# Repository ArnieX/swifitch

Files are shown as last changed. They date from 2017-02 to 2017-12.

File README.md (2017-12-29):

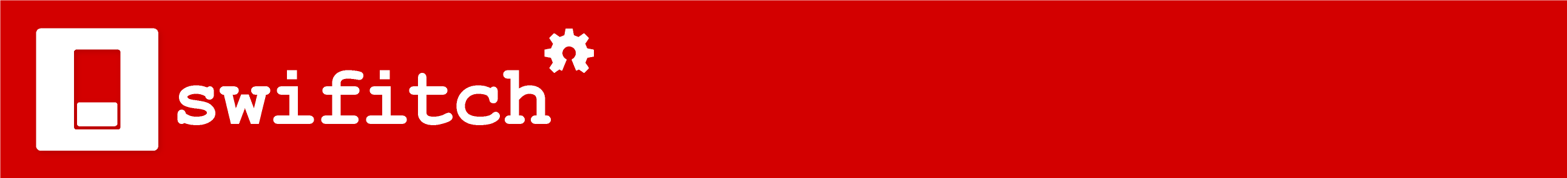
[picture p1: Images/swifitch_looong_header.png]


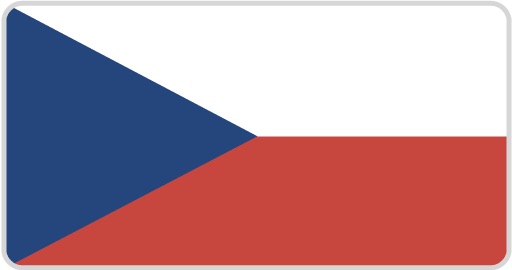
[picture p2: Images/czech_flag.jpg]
||[Readme v Češtině](https://github.com/ArnieX/swifitch/blob/master/README_CZ.md)|
|---|---|

## Table of contents

- [Introduction](https://github.com/ArnieX/swifitch#introduction)
	- [What is it?](https://github.com/ArnieX/swifitch#what-is-it)
	- [What can it do?](https://github.com/ArnieX/swifitch#what-can-it-do)
	- [What is expected cost?](https://github.com/ArnieX/swifitch#what-is-expected-cost)
	- [How does it look like?](https://github.com/ArnieX/swifitch#how-does-it-look-like)
	- [How big is it?](https://github.com/ArnieX/swifitch#how-big-is-it)
	- [Is it safe?](https://github.com/ArnieX/swifitch#is-it-safe)
	- [OK I'm sold! What do I need to build it?](https://github.com/ArnieX/swifitch#ok-im-sold-what-do-i-need-to-build-it)
- [SeeedStudio Fusion PCB](https://github.com/ArnieX/swifitch#seeedstudio-fusion-pcb)
	- [How to order PCBs](https://github.com/ArnieX/swifitch#how-to-order-pcbs)
-  [After you build it](https://github.com/ArnieX/swifitch#after-you-build-it)
	- [OK DONE! What's next?](https://github.com/ArnieX/swifitch#ok-done-whats-next)
- [Software](https://github.com/ArnieX/swifitch#software)
	- [Swifitch default software](https://github.com/ArnieX/swifitch#swifitch-default-software)
	- [Custom software](https://github.com/ArnieX/swifitch#custom-software)
- [Enclosure](https://github.com/ArnieX/swifitch#enclosure)
	- [3D Printed](https://github.com/ArnieX/swifitch#3d-printed)
	- [Purchased ABS box](https://github.com/ArnieX/swifitch#purchased-abs-box)
- [Soldering cheatsheet](https://github.com/ArnieX/swifitch#soldering-cheatsheet)
	- [Back side](https://github.com/ArnieX/swifitch#back-side)
	- [Front side](https://github.com/ArnieX/swifitch#front-side)
- [Credits](https://github.com/ArnieX/swifitch#credits)
- [What's next?](https://github.com/ArnieX/swifitch#whats-next)
- [Photos](https://github.com/ArnieX/swifitch#photos)

# Introduction

### What is it?

ESP8266 based WiFi enabled relay board, that will let you easily turn any light or any plug to SMART one. Easily control using HomeKit (other HW needed) or using any MQTT based SmartHome application. Or if you are skilled developer, write any code you want.

### What can it do?

Main purpose is to turn things ON or OFF. But it can do lot more than that, swifitch is equiped with header to connect another 4 digital devices and 1 analog. These could be sensors etc.

If you need, by sacrificing one of the data pins, you can get 5V for your 5V sensors.

**⛔  Be aware that swifitch's pins are not 5V tolerant and cannot accept 5V on any of the pins provided, and it will damage the ESP.**

There are also two jumpers. One is for enabling deep sleep and the other is to put ESP into flash mode when you use conventional USB2UART programmer. We have reused one NodeMCU to make a lot more convenient programmer out of it, because it handles resets and flash mode boot automatically. Details will follow.

### What is expected cost?

We have designed swifitch to be both cheap and safe. So it is not ultra cheap but not expensive too. **Our cost calculations has stoped at $8!** Not bad, what you think?

### How does it look like?

Definitely beautiful!!

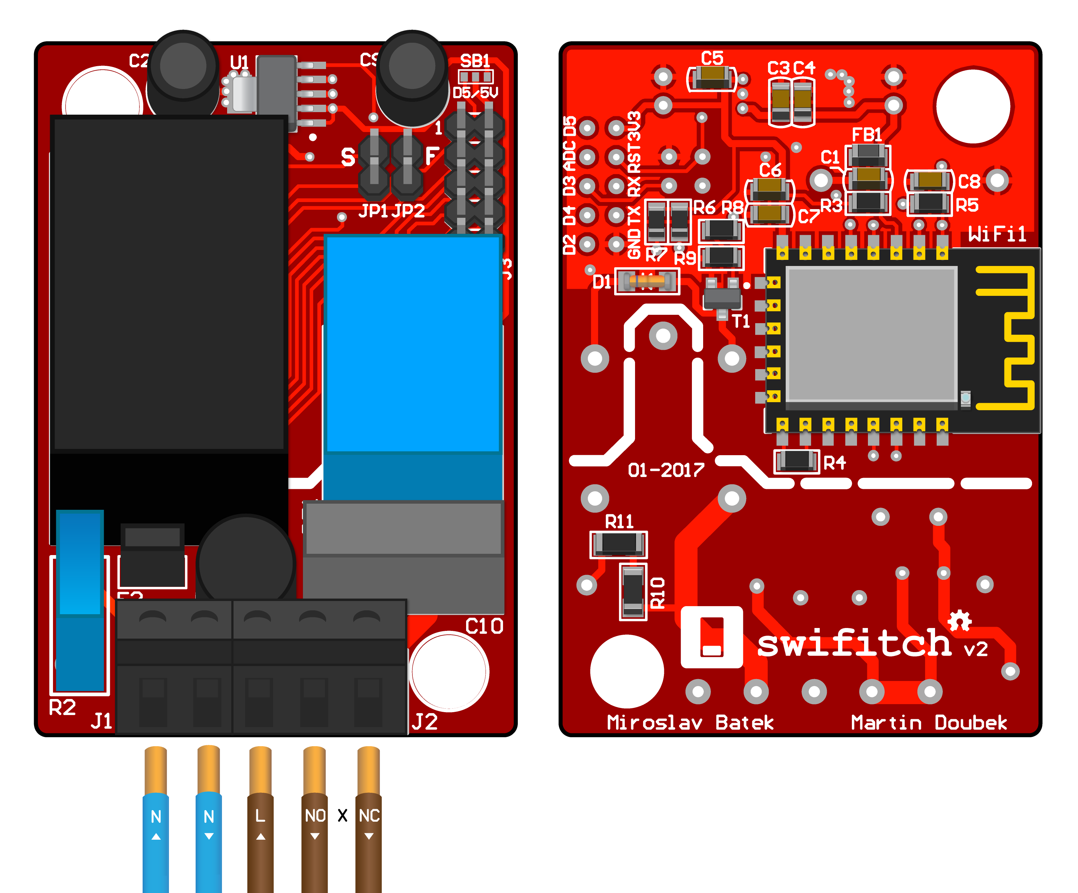
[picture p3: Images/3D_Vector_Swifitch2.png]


### How big is it?

Actually very small, you should be able to fit it almost anywhere without any hassle. But I know, numbers tell it all, so here it is.

|**Width**|**Height**|**Depth**|**Weight W/O BOX**|**Weight W/ BOX**|
|---|---|---|---|---|
| 42mm / 1.65" | 60.5mm / 2.36" | 19.6mm / 0.77" | ~42g / ~1.48oz | ~72g / ~2.54oz  |

### Is it safe?

We have designed few safety features in swifitch. Most important are fuses on mains input. There is one overcurrent fuse and one overvoltage fuse (surge protection), and more importantly temperature fuse that will disconnect swifitch from mains input when temperature raises above 100°C. There should be another few safeties in HLK-PM01 but we didn't want to depend on it's quality. 

### OK I'm sold! What do I need to build it?

**Capacitors**

|Preview|Part|Buy|
|---|---|---|
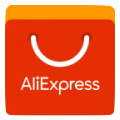
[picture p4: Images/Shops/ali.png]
||4.7μF 0805|[](http://swifitch.cz/capacitors_4.7uf_0805)|
||100nF 0805|[](http://swifitch.cz/capacitors_100nf_0805)|
||10nF 0805|[](http://swifitch.cz/capacitory_10nf_0805)|
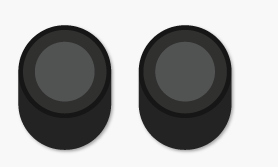
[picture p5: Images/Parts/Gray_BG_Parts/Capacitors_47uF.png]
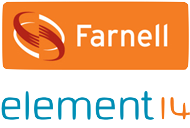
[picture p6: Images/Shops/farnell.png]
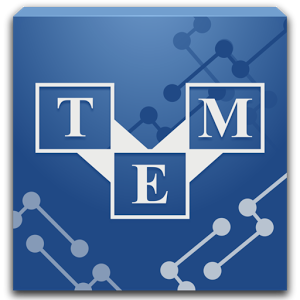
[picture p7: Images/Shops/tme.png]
||47μF ⌀6.3x5mm|[](http://swifitch.cz/capacitors_47uf_6.3x5_farnell) [](http://swifitch.cz/capacitors_47uf_6.3x5_tme)|
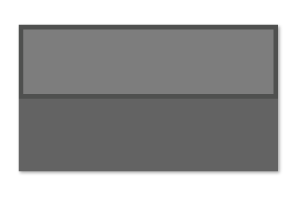
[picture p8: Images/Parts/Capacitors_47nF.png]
||47nF X2|[](http://swifitch.cz/capacitors_47nf_farnell) [](http://swifitch.cz/capacitors_47nf_tme)|

**Resistors**

|Preview|Part|Buy|
|---|---|---|
||10kΩ 0805|[](http://swifitch.cz/resistors_10k_0805)|
||1.5kΩ 0805|[](http://swifitch.cz/resistors_1.5k_0805)|
||2.2kΩ 0805|[](http://swifitch.cz/resistors_2.2k_0805)|
||47kΩ 0805|[](http://swifitch.cz/resistors_47k_0805)|
||160Ω 1206|[](http://swifitch.cz/resistors_160R_1206)|
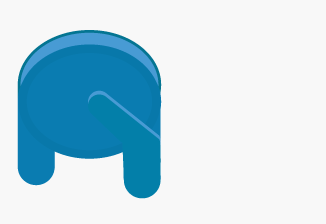
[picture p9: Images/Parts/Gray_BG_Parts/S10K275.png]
||S10K275|[](http://swifitch.cz/resistors_S10K275_farnell) [](http://swifitch.cz/resistors_S10K275_tme)|

**Power and Controls**

|Preview|Part|Buy|
|---|---|---|
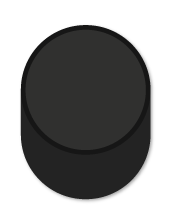
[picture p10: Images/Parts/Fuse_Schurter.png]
||SCHURTER MST 250VAC 500mA|[](http://swifitch.cz/power_schurter_fuse_farnell) [](http://swifitch.cz/power_schurter_fuse_tme)|
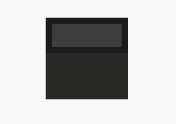
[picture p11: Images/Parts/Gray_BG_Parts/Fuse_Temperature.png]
||PROFFUSE TZ-P100/2 100°C or similar|[](http://swifitch.cz/power_temperature_fuse_farnell) [](http://swifitch.cz/power_temperature_fuse_tme)|
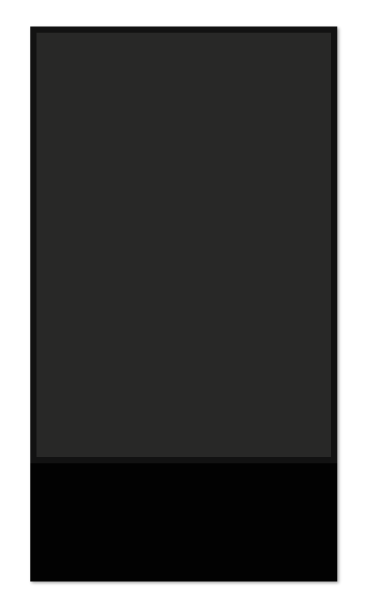
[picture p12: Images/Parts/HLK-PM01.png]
||Hi-Link HLK-PM01 AC-DC 5V/3W|[](http://swifitch.cz/power_AC_DC)|
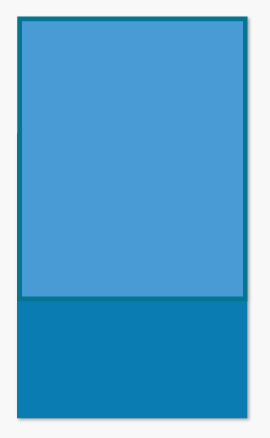
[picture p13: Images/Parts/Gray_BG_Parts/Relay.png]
||SRD-05VDC-SL-C Relay<br>FINDER  36.11.9.005.4011|[](http://swifitch.cz/power_relay_ali) [](http://swifitch.cz/power_relay_farnell) [](http://swifitch.cz/power_relay_tme)|

**Other SMD Parts**

|Preview|Part|Buy|
|---|---|---|
||BC817-16.215|[](http://swifitch.cz/smd_bc817_ali) [](http://swifitch.cz/smd_bc817_farnell) [](http://swifitch.cz/smd_bc817_tme)|
||BAS86|[](http://swifitch.cz/smd_bas86_farnell) [](http://swifitch.cz/smd_bas86_tme)|
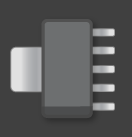
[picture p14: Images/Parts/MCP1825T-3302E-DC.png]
||MCP1825T-3302E/DC Voltage Regulator|[](http://swifitch.cz/smd_MCP1825T_farnell) [](http://swifitch.cz/smd_MCP1825T_tme)|
||Ferrite Bead 600Ω 100MHz 0805|[](http://swifitch.cz/smd_ferritebead_ali) [](http://swifitch.cz/smd_ferritebead_farnell) [](http://swifitch.cz/smd_ferritebead_tme)|
||Any 0805 LED diode|[](http://swifitch.cz/smd_led_diode)|

**Connectors**

|Preview|Part|Buy|
|---|---|---|
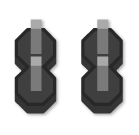
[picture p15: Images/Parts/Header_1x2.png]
||Headers 1x2 2.54mm pitch|[](http://swifitch.cz/connector_headers_1x2)|
||Headers 2x5 2.54mm pitch|[](http://swifitch.cz/connector_headers_2x5)|
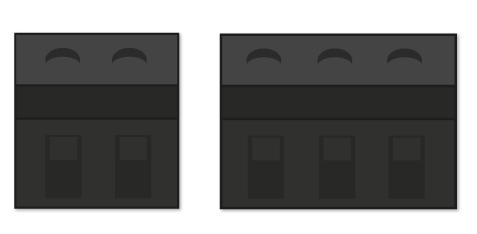
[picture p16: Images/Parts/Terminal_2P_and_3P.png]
||Terminal 2P and 3P, 5.08mm pitch rounded lead|[](http://swifitch.cz/connector_terminal)|

**The rest**

|Preview|Part|Buy|
|---|---|---|
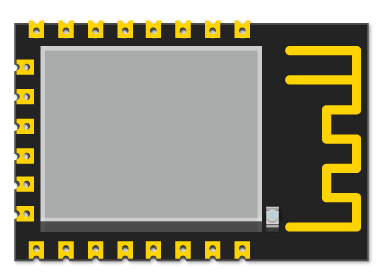
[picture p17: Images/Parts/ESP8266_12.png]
||ESP8266-12(E/F/S)|[](http://swifitch.cz/therest_esp8266)|
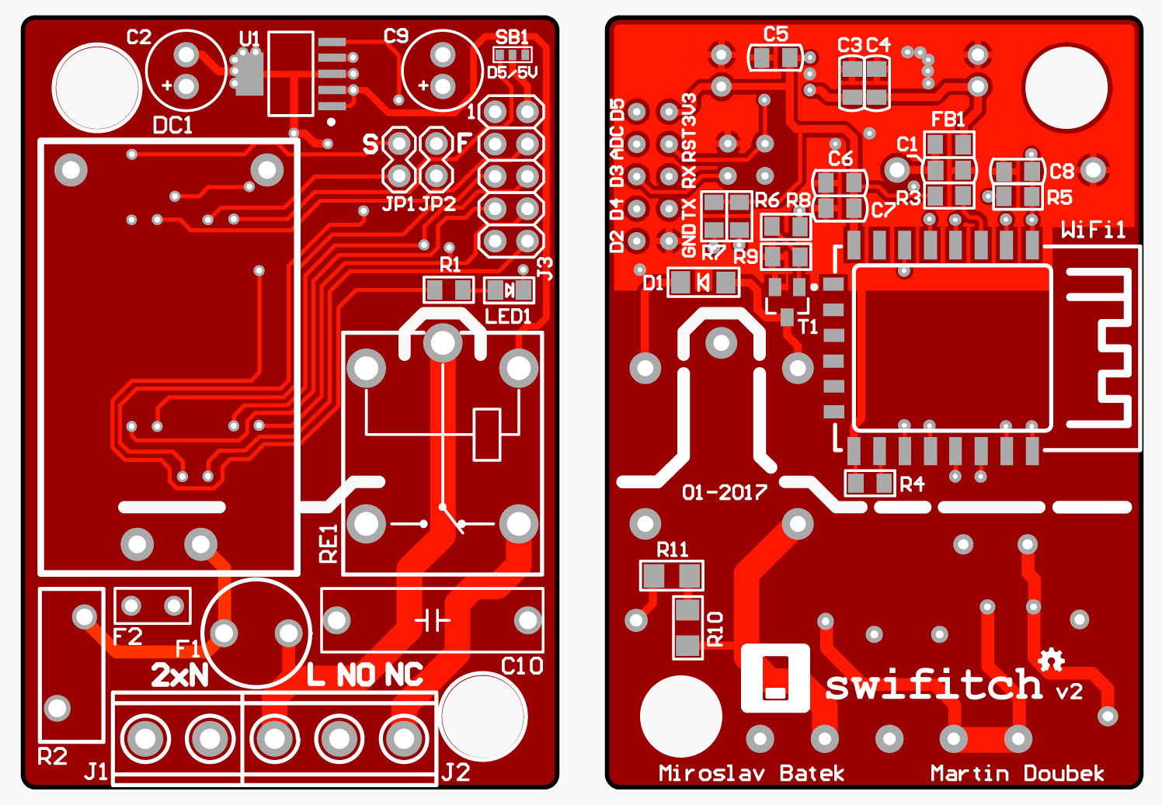
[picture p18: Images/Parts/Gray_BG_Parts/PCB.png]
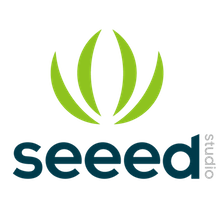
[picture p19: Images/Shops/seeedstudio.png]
||PCB|[](http://swifitch.cz/therest_pcb)|

Most of it could be purchased on AliExpress or eBay for what we call "no money", some parts are safer to get from your local trusted electricians shop (fuse and relay if you do not want chinese).

Most AliExpress links in table above are tested and trusted sellers, but we do not give any guarantees.

TME.eu is good source for EU citizens and especially guys in Czech Republic.

Farnell should be OK for all over world.

# SeeedStudio Fusion PCB

### How to order PCBs

First grab gerber files ZIP and upload it to [SeeedStudio Fusion PCB](http://swifitch.cz/therest_pcb) then follow instructions below.

We have created sreenshots from ordering process so you can recreate the process in same manner. Decide how many pieces you want and get started. Keep in mind that each board are actually two swifitches ;). That makes it even cheaper.

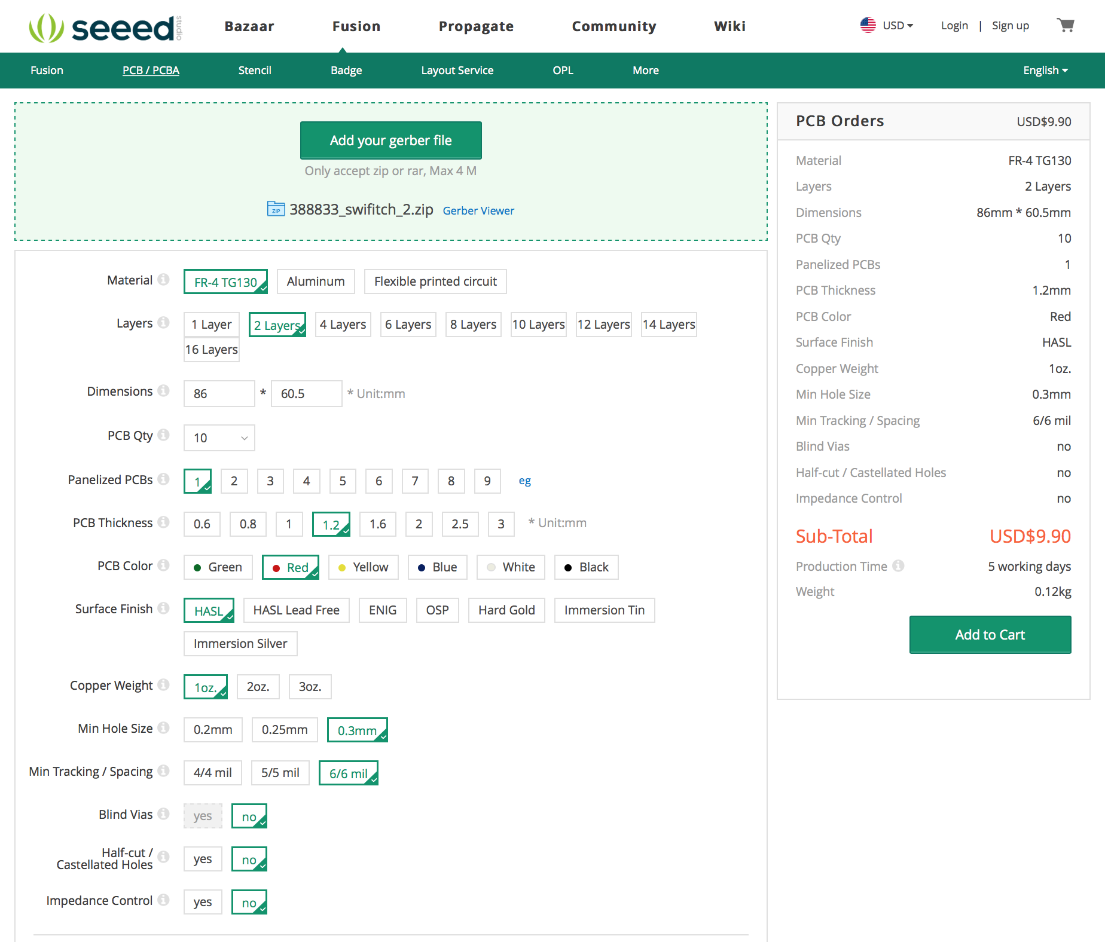
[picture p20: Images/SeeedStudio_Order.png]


Gerber files preview:

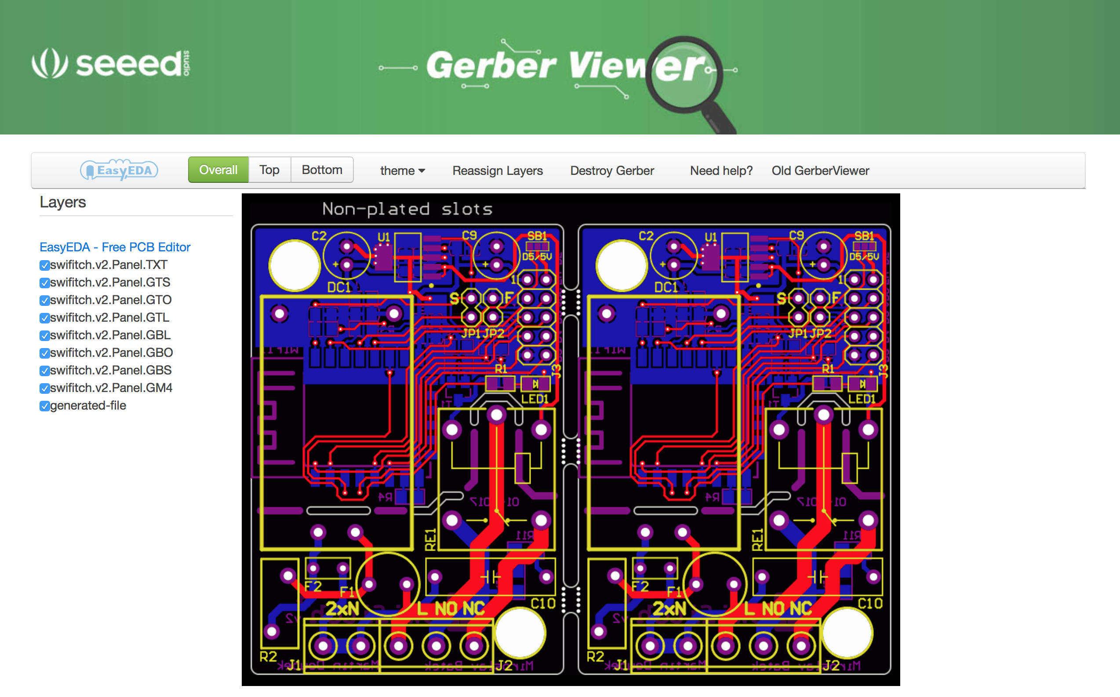
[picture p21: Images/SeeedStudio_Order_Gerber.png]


# After you build it

### OK DONE! What's next?

Now you need to flash some software to it. Either use conventional CP2102 USB2UART programmer or build your own as we did from NodeMCU, it is definitely best option you have.

This image tell you all you need to know but basically this is the list of steps:

- Desolder ESP8266 from NodeMCU (Heatgun baby!! But carefully you can use it for swifitch then.)
- Solder colored wires to the contacts according to image below
- Insert these wires to 2x5, 2.54mm pitch connector
- Connect to swifitch and flash firmware

We have created software for you to get started quicky so go to it's own [repository](http://swifitch.cz/software).

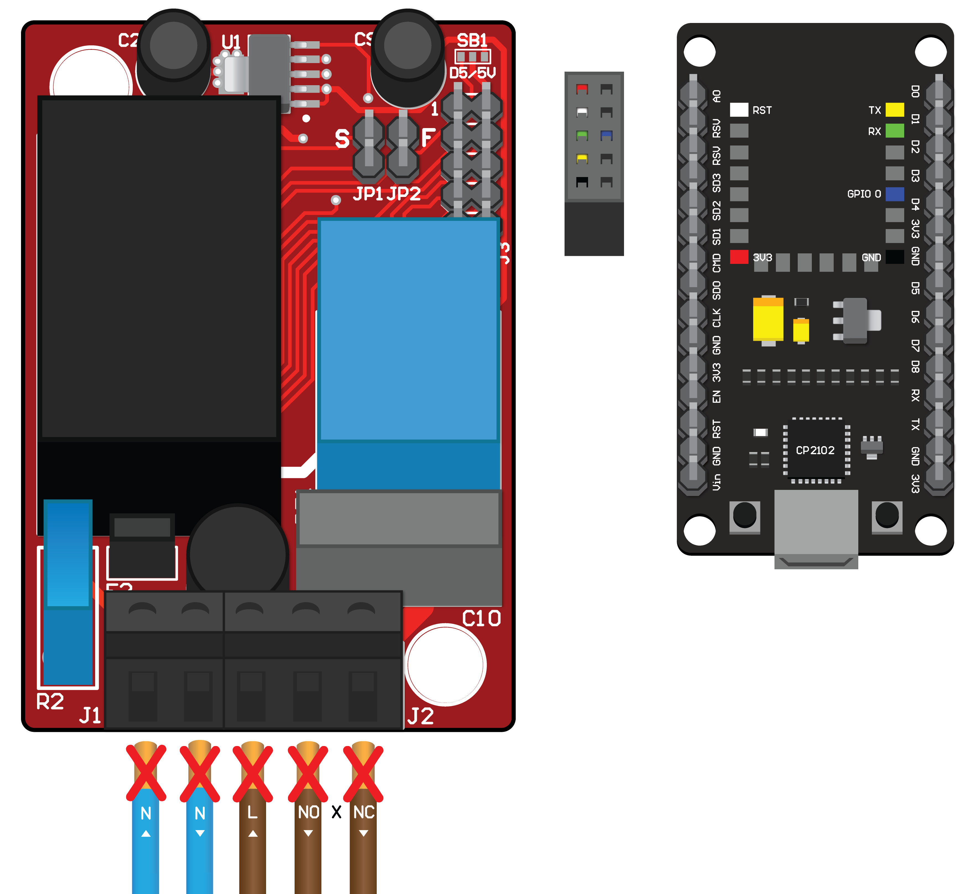
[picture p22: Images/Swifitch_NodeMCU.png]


**⚡ DO NOT CONNECT SWIFITCH TO MAINS VOLTAGE WHEN FLASHING ⚡**

It should be safe, but we do not recommend it!

# Software

### Swifitch default software

If you went with our software you are good to go, just follow the README in the [repository](http://swifitch.cz/software).

### Custom software

Just few things you need to know if you develop your own software.

- Relay is controled by D1 or GPIO5 PIN
- Built in LED is controled by D6 or GPIO12 PIN

# Enclosure

### 3D Printed

If you have access to 3D printer, have a look at our original swifitch box.

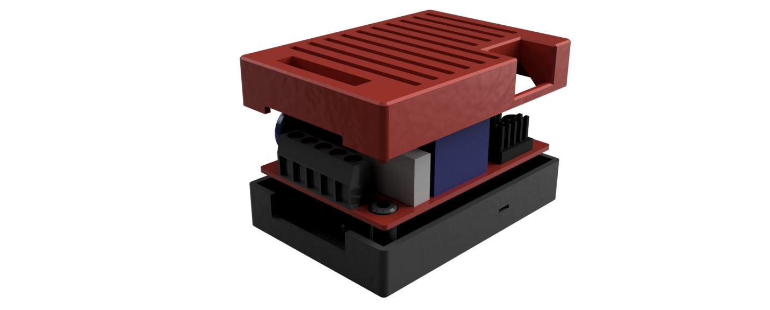
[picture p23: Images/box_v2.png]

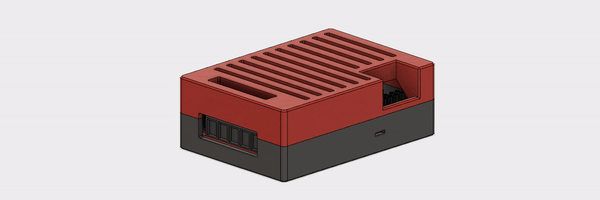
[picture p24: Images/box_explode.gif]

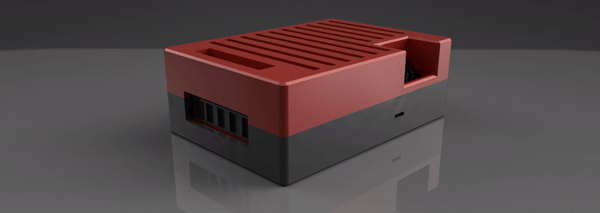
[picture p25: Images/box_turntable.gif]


If you wish to design your own box and you use Fusion 360, here is 3D model of [Swifitch](http://a360.co/2kX4JSr).

Use ABS plastic filament as this device is using mains voltage and ABS is safer for such devices.

**DO NOT USE CONDUCTIVE FILAMENTS**

### Purchased ABS box

We have fitted swifitch to box that can be [purchased](http://swifitch.cz/enclosure) from various electrical shops. May not be available in all countries thought.

# Soldering cheatsheet

### Back side

Start with SMD parts on the BACK side.

**Capacitors**

|Slot|Part|
|---|---|
|C1|4.7μF|
|C3|4.7μF|
|C5|4.7μF|
|C6|4.7μF|
|C4|100nF|
|C7|100nF|
|C8|10nF|

**Resistors**

|Slot|Part|
|---|---|
|R3|10kΩ|
|R4|10kΩ|
|R5|10kΩ|
|R6|10kΩ|
|R7|10kΩ|
|R8|2.2kΩ|
|R9|47kΩ|
|R10|160Ω|
|R11|160Ω|

**The rest**

|Slot|Part|
|---|---|
|FB1|FB 600Ω 100MHz|
|D1|BAS86|
|T1|BC817|
|WiFi1|ESP8266-12(E/F/S)|

### Front side

Front side contains mostly THT parts, but start with SMD parts that would be harder to solder when you finish all bigger parts.

**SMD**

|Slot|Part|
|---|---|
|R1|470Ω < Rled < 2kΩ (depends on LED1)|
|LED1|Choose color you like|
|V1|Voltage Regulator|

**THT**

|Slot|Part|
|---|---|
|DC1|HLK-PM01|
|F2|100°C fuse|
|R2|S10K275|
|F1|MST250/0.5A|
|C10|47nF|
|C2|47μF|
|C9|47μF|
|SB1|Optionaly enable D5 or 5V|
|JP1|1x2 header|
|JP2|1x2 header|
|J3|2x5 header|
|RE1|Relay|
|J1|2P terminal|
|J2|3P terminal|

**🎉 DONE 🎉**

# Credits

- PCB design, electronics ideas, parts selection - Miroslav Batěk
- SW, Git Repo, design, 3D printed enclosure - Martin Doubek

# Mentions

Yellow Couch

(https://youtu.be/TU_wt0HFtbs)

Czech - with **English** subtitles

# What's next?

If you liked swifitch and want to submerge deeper into IoT we will reference some other projects here.

- [tjclement's ESP8266 dimmer HW for LED Strips](https://github.com/tjclement/esp-dimmer-hardware)

IoT platforms and enablers.

- [Homebridge - HomeKit server](https://github.com/nfarina/homebridge)
	- [Homebridge MQTT plugin](https://github.com/cflurin/homebridge-mqtt)
- [Blynk - platform and applications for IoT - Swifitch is supported](https://github.com/blynkkk/blynk-server)
- [Soldering timelapse from one of our builders - YouTube](https://www.youtube.com/watch?v=yz-Ut0sAMPU)

# Photos

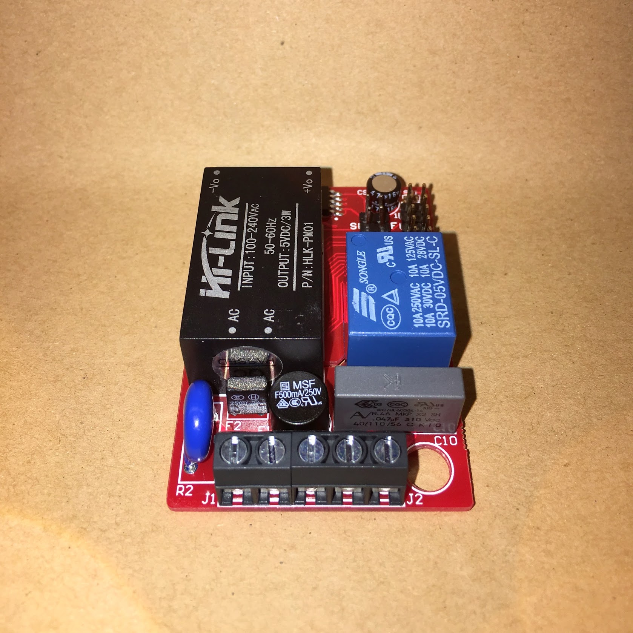
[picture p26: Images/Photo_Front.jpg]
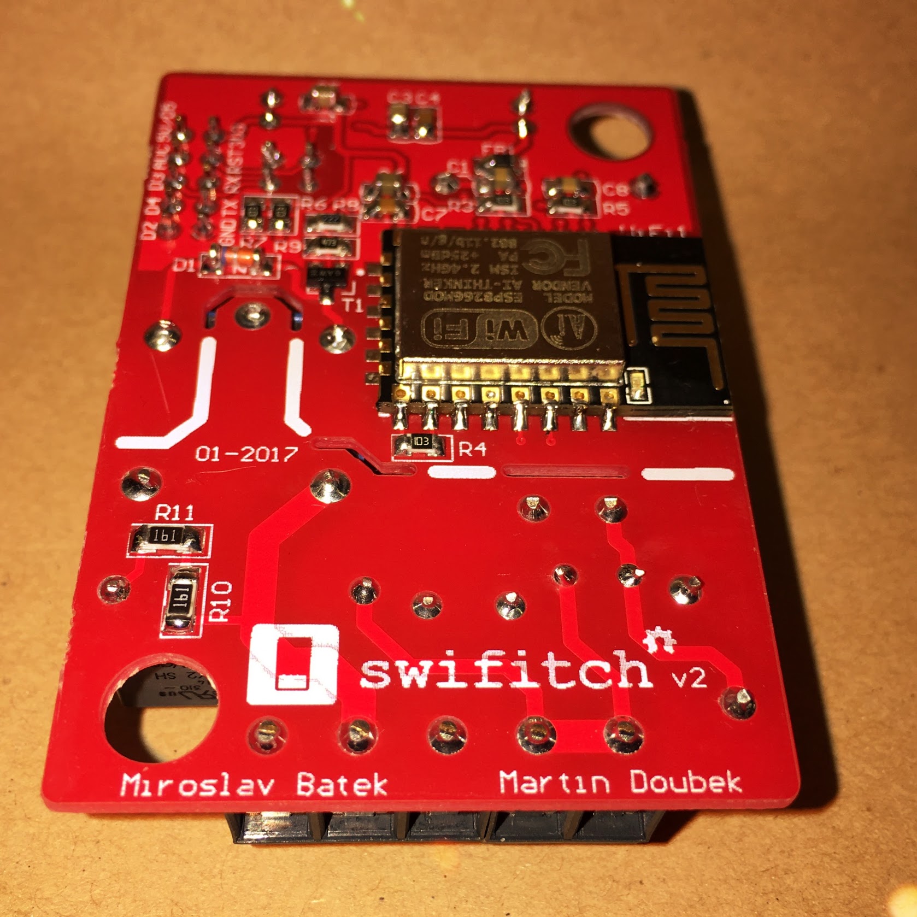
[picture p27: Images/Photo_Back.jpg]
 
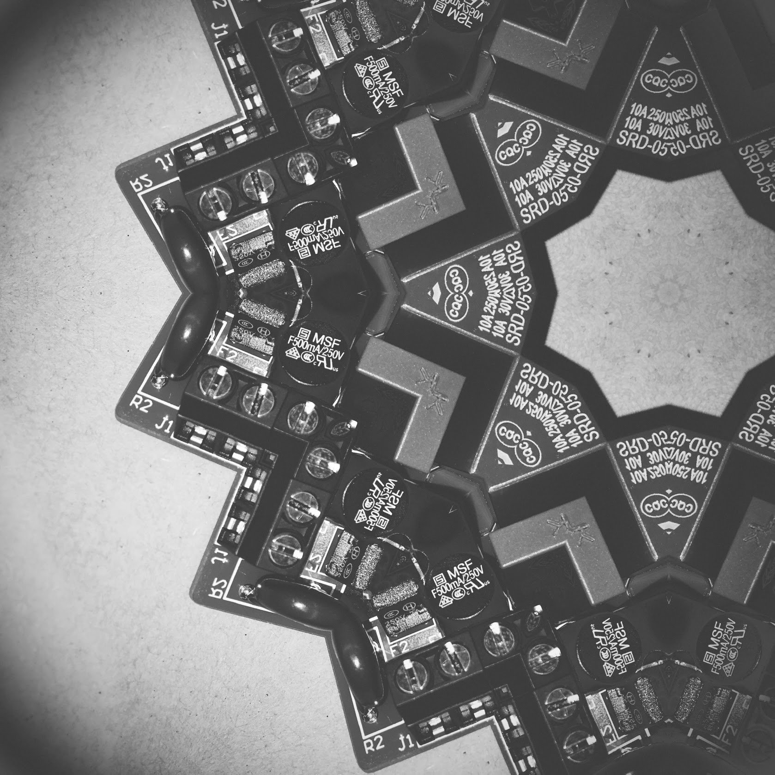
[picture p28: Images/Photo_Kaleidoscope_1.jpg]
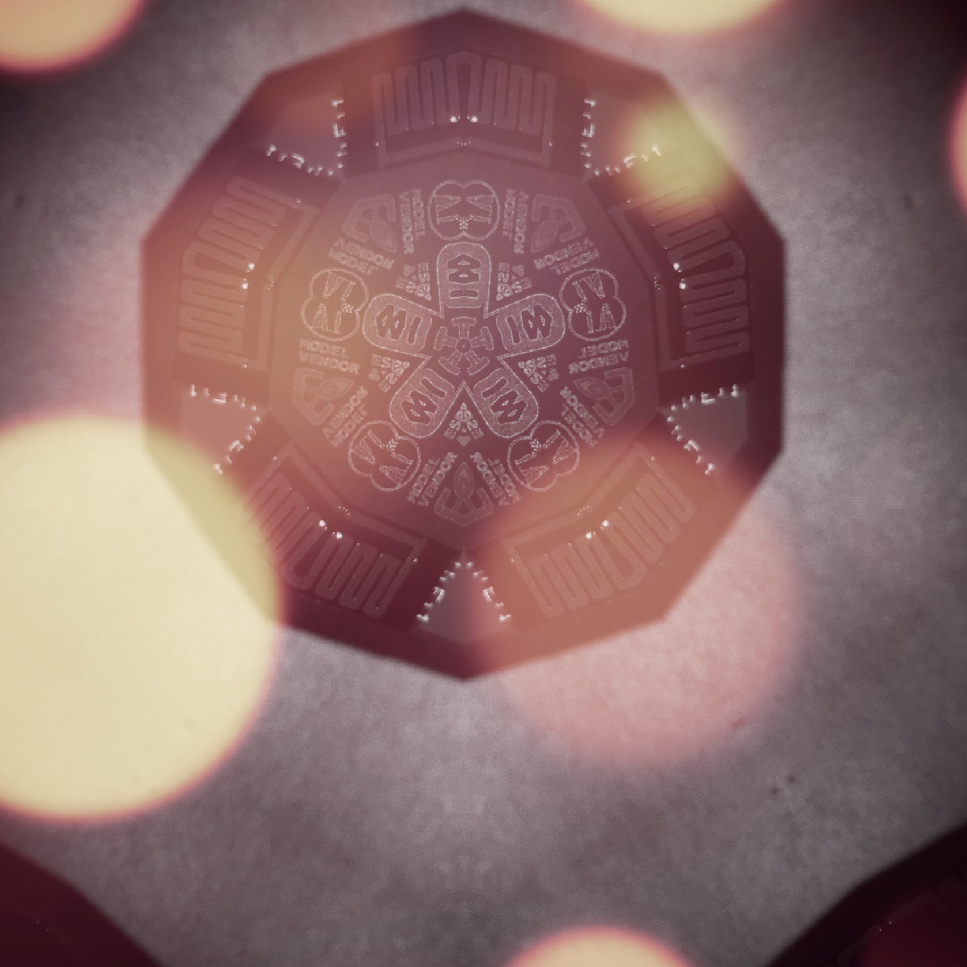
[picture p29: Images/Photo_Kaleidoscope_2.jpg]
 
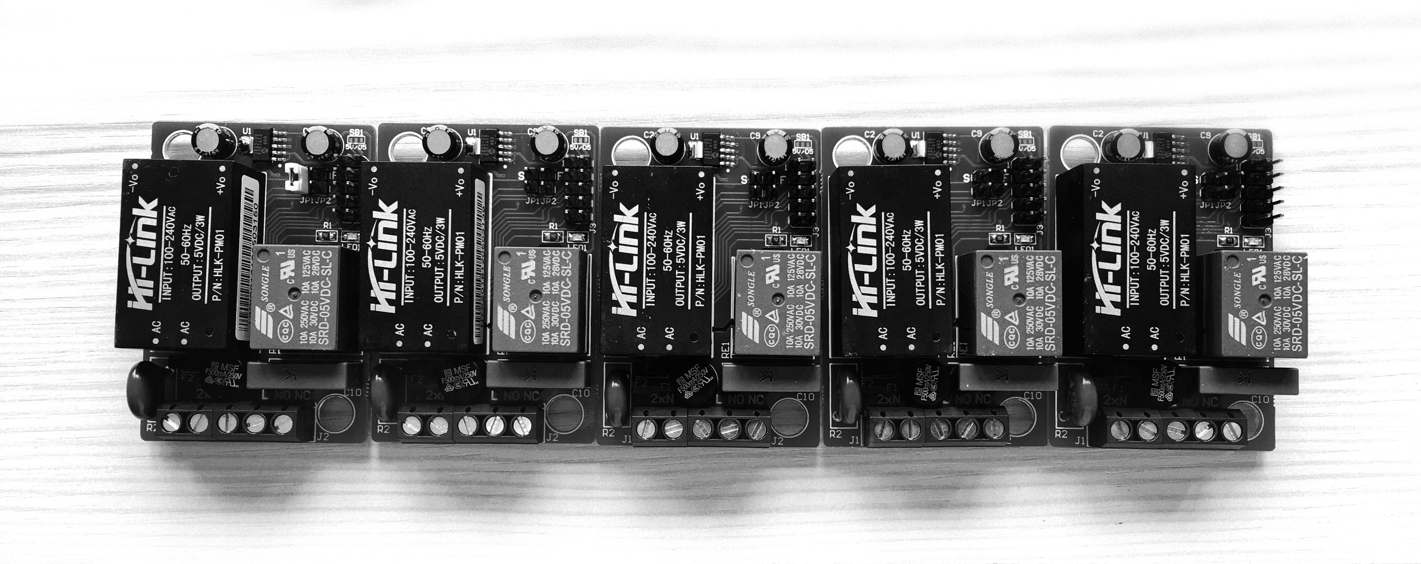
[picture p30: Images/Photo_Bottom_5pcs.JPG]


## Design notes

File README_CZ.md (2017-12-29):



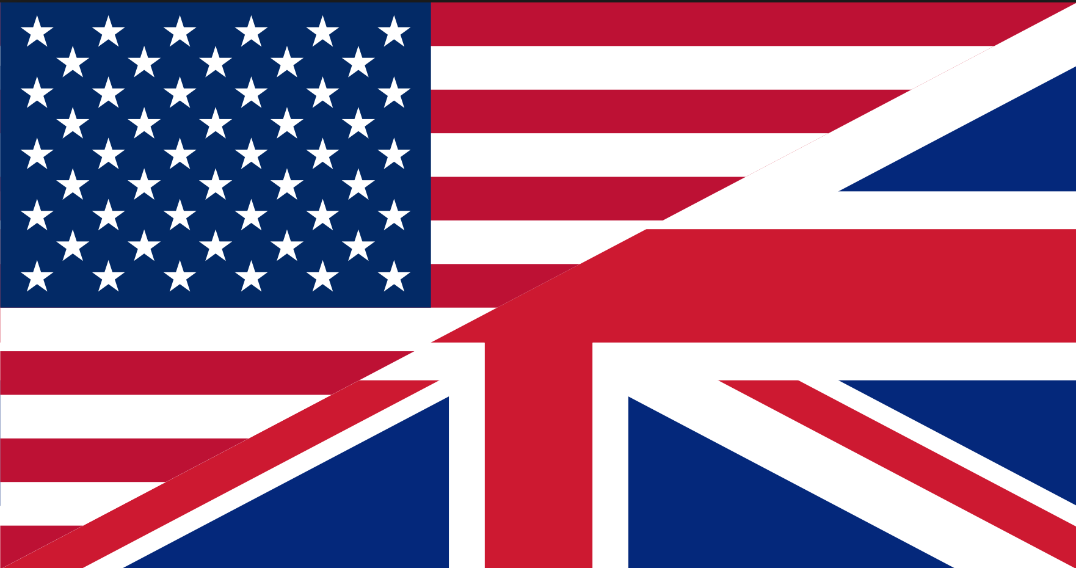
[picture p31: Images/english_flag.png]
||[Readme in English](https://github.com/ArnieX/swifitch/blob/master/README.md)|
|---|---|

## Obsah

- [Úvod](https://github.com/ArnieX/swifitch/blob/master/README_CZ.md#úvod)
	- [Co to je?](https://github.com/ArnieX/swifitch/blob/master/README_CZ.md#co-to-je)
	- [Co to umí?](https://github.com/ArnieX/swifitch/blob/master/README_CZ.md#co-to-umí)
	- [Na kolik to vyjde?](https://github.com/ArnieX/swifitch/blob/master/README_CZ.md#na-kolik-to-vyjde)
	- [Jak to vypadá?](https://github.com/ArnieX/swifitch/blob/master/README_CZ.md#jak-to-vypadá)
	- [Jak je to velké?](https://github.com/ArnieX/swifitch/blob/master/README_CZ.md#jak-je-to-velké)
	- [Co bezpečnost?](https://github.com/ArnieX/swifitch/blob/master/README_CZ.md#co-bezpečnost)
	- [Chci to! Co potřebuji koupit?](https://github.com/ArnieX/swifitch/blob/master/README_CZ.md#chci-to-co-potřebuji-koupit)
- [SeeedStudio Fusion PCB](https://github.com/ArnieX/swifitch/blob/master/README_CZ.md#seeedstudio-fusion-pcb)
	- [Jak objednat plošné spoje](https://github.com/ArnieX/swifitch/blob/master/README_CZ.md#jak-objednat-plošné-spoje)
-  [Po sestavení](https://github.com/ArnieX/swifitch/blob/master/README_CZ.md#po-sestavení)
	- [Hotovo! Co dál?](https://github.com/ArnieX/swifitch/blob/master/README_CZ.md#hotovo-co-dál)
- [Software](https://github.com/ArnieX/swifitch/blob/master/README_CZ.md#software)
	- [Náš základní software](https://github.com/ArnieX/swifitch/blob/master/README_CZ.md#náš-základní-software)
	- [Vlastní software](https://github.com/ArnieX/swifitch/blob/master/README_CZ.md#vlastní-software)
- [Krabička](https://github.com/ArnieX/swifitch/blob/master/README_CZ.md#krabička)
	- [Vytištěná na 3D tiskárně](https://github.com/ArnieX/swifitch/blob/master/README_CZ.md#vytištěná-na-3d-tiskárně)
	- [Kupovaná krabička](https://github.com/ArnieX/swifitch/blob/master/README_CZ.md#kupovaná-krabička)
- [Návod na pájení](https://github.com/ArnieX/swifitch/blob/master/README_CZ.md#návod-na-pájení)
	- [Zadní strana](https://github.com/ArnieX/swifitch/blob/master/README_CZ.md#zadní-strana)
	- [Přední strana](https://github.com/ArnieX/swifitch/blob/master/README_CZ.md#přední-strana)
- [Zásluhy](https://github.com/ArnieX/swifitch/blob/master/README_CZ.md#zásluhy)
- [Co dál?](https://github.com/ArnieX/swifitch/blob/master/README_CZ.md#co-dál)
- [Fotografie](https://github.com/ArnieX/swifitch/blob/master/README_CZ.md#fotografie)

# Úvod

### Co to je?

Swifitch je zjednodušeně WiFi spínač, založený na známém modulu ESP8266 ve verzi 12(E,F,S) a umožní vám proměnit jakékoliv světlo nebo zásuvku v dálkově ovládanou. Pak lze ovládat přes HomeKit (Potřeba dalšího zařízení - serveru) nebo přes jakoukoliv aplikaci, která umožňuje ovládání přes protokoly MQTT nebo HTTP. Velice záleží na softwaru, který si do zařízení nahrajete.

### Co to umí?

Jak už z názvu vyplývá hlavní funkcí je připojené zařízení zapínat nebo vypínat. Tím to ale nekončí, přidali jsme rozhraní pro připojení dalších 4 digitálních a jednoho analogového zařízení, tím může být prakticky cokoliv, teplotní čidlo, senzor pohybu nebo jiný senzor či modul.

Obětováním jednoho datového pinu lze získat 5V pro senzory nebo jiné moduly vyžadujících pro svou činnost 5V.

**⛔  Pozor, swifitch přesto, že umožňuje aktivaci výstupu 5V neumožňuje vstup 5V na žádném dostupném pinu, pokud byste připojili 5V na některý pin, zničíte modul ESP8266.**

Kromě vstupně-výstupních pinů jsou k dispozici také dvě přemostění, první umožňuje využití režimu hlubokého spánku, druhé je nezbytné pokud pro nahrávání softwaru budete využívat běžný USB2UART programátor. Naše doporučení je využít pro programování upravený NodeMCU vývojový modul a to proto, že se sám stará o aktivaci flashovacího režimu a restarty modulu, víc dále.

### Na kolik to vyjde?

Navrhli jsme swifitch aby byl levný a zároveň bezpečný, takže není ani extrémně levný, ale ani drahý. **Celková konečná cena druhé verze je přibližně 215Kč!** To není zlé co myslíte?

### Jak to vypadá?

Naprosto a jednoznačně krásně!



### Jak je to velké?

Velké ani ne, spíše malé. Neměl by být problém napasovat swifitch kamkoliv jej budete chtít umístit. Je mi to jasné, čísla to poví lépe.

|**Šířka**|**Výška**|**Hloubka**|**Váha bez krabičky**|**Váha s krabičkou**|
|---|---|---|---|---|
| 42mm | 60.5mm | 19.6mm | ~42g | ~72g |

### Co bezpečnost?

Při navrhování swifitche byla bezpečnost jednou z priorit a rozhodně jsme ji nezanedbali. Hlavní bezpečnostní prvky jsou na vstupu z rozvodné sítě. Je zde pojistka proti nadměrnému odběru (zkratu), pojistka proti přepětí a teplotní pojistka, která vypne napájení při překročení teploty 100°C. Další pojistné mechanismy by měl obsahovat přímo zdroj HLK-PM01, nechtěli jsme však spoléhat na jejich kvalitu.

### Chci to! Co potřebuji koupit?

**Kondenzátory**

|Náhled|Součástka|Koupit|
|---|---|---|
||4.7μF 0805|[](http://swifitch.cz/capacitors_4.7uf_0805)|
||100nF 0805|[](http://swifitch.cz/capacitors_100nf_0805)|
||10nF 0805|[](http://swifitch.cz/capacitory_10nf_0805)|
||47μF ⌀6.3x5mm|[](http://swifitch.cz/cz/capacitors_47uf_6.3x5_farnell) [](http://swifitch.cz/cz/capacitors_47uf_6.3x5_tme)|
||47nF X2|[](http://swifitch.cz/cz/capacitors_47nf_farnell) [](http://swifitch.cz/cz/capacitors_47nf_tme)|

**Odpory**

|Náhled|Součástka|Koupit|
|---|---|---|
||10kΩ 0805|[](http://swifitch.cz/resistors_10k_0805)|
||1.5kΩ 0805|[](http://swifitch.cz/resistors_1.5k_0805)|
||2.2kΩ 0805|[](http://swifitch.cz/resistors_2.2k_0805)|
||47kΩ 0805|[](http://swifitch.cz/resistors_47k_0805)|
||160Ω 1206|[](http://swifitch.cz/resistors_160R_1206)|
||S10K275|[](http://swifitch.cz/cz/resistors_S10K275_farnell) [](http://swifitch.cz/cz/resistors_S10K275_tme)|

**Napájení a ovládací prvky**

|Náhled|Součástka|Koupit|
|---|---|---|
||SCHURTER MST 250VAC 500mA|[](http://swifitch.cz/cz/power_schurter_fuse_farnell) [](http://swifitch.cz/cz/power_schurter_fuse_tme)|
||PROFFUSE TZ-P100/2 100°C nebo podobná|[](http://swifitch.cz/cz/power_temperature_fuse_farnell) [](http://swifitch.cz/cz/power_temperature_fuse_tme)|
||Hi-Link HLK-PM01 AC-DC 5V/3W|[](http://swifitch.cz/power_AC_DC)|
||SRD-05VDC-SL-C relé<br>FINDER  36.11.9.005.4011|[](http://swifitch.cz/power_relay_ali) [](http://swifitch.cz/cz/power_relay_farnell) [](http://swifitch.cz/cz/power_relay_tme)|

**Další SMD součástky**

|Náhled|Součástka|Koupit|
|---|---|---|
||BC817-16.215|[](http://swifitch.cz/smd_bc817_ali) [](http://swifitch.cz/cz/smd_bc817_farnell) [](http://swifitch.cz/cz/smd_bc817_tme)|
||BAS86|[](http://swifitch.cz/cz/smd_bas86_farnell) [](http://swifitch.cz/cz/smd_bas86_tme)|
||MCP1825T-3302E/DC Regulátor Napětí|[](http://swifitch.cz/cz/smd_MCP1825T_farnell) [](http://swifitch.cz/cz/smd_MCP1825T_tme)|
||Feritová perla 600Ω 100MHz 0805|[](http://swifitch.cz/smd_ferritebead_ali) [](http://swifitch.cz/cz/smd_ferritebead_farnell) [](http://swifitch.cz/cz/smd_ferritebead_tme)|
||Libovolná 0805 LED dioda|[](http://swifitch.cz/smd_led_diode)|

**Konektory**

|Náhled|Součástka|Koupit|
|---|---|---|
||Oboustranný kolík 1x2 s roztečí 2.54mm |[](http://swifitch.cz/connector_headers_1x2)|
||Oboustranný kolík 2x5 s roztečí 2.54mm|[](http://swifitch.cz/connector_headers_2x5)|
||Svorkovnice 2P a 3P, s roztečí 5.08mm a kulatým vývodem|[](http://swifitch.cz/connector_terminal)|

**Zbytek**

|Náhled|Součástka|Koupit|
|---|---|---|
||ESP8266-12(E/F/S)|[](http://swifitch.cz/therest_esp8266)|
||Plošné spoje|[](http://swifitch.cz/therest_pcb)|

Většinu lze zakoupit na AliExpressu nebo eBay a to za ceny, že ani není třeba to komentovat. Některé součástky je lepší nebo i výhodnější zakoupit od místních prodejců elektroniky.

Většina odkazů na jednotlivé díly v tabulkách výše je prověřená, nicméně neposkytujeme žádné záruky.

Pro nás Čechy a popř. Slováky, bude dobrým zdrojem většiny dílů, které nelze zakoupit přes Alíka obchod TME.eu, poštovné je také za hubičku.

Pro ty ostatní je zde ještě Farnell

# SeeedStudio Fusion PCB

### Jak objednat plošné spoje

Stáhněte si ZIP soubor obsahující soubory "Gerber" a celý jej nahrajte do objednávacího procesu na [SeeedStudio Fusion PCB webu](http://swifitch.cz/therest_pcb) a postupujte podle instrukcí na webu a níže.

Připravili jsme pro vás snímky obrazovky z objednávkového procesu, když jsme plošné spoje objednávali naposledy a tak můžete snadno vyplnit stejné hodnoty. Vyberte si počet plošných spojů a mějte na paměti, že 1ks jsou dva. Za stejnou cenu se nám podařilo na jednu desku dostat dvě.



Náhled na obsah Gerber souborů:



# Po sestavení

### Hotovo! Co dál?

Po sestavení přichází na řadu nahrání softwaru. Můžete buďto použít běžný USB2UART programátor nebo vyrobit vlastní úpravou NodeMCU. Je to levná varianta, efektivní a ještě získáte jeden modul ESP8266 na výrobu swifitche.

Obrázek níže přesně ukazuje čeho potřebujete dosáhnout, přesto pár kroků jak na to.

- Pomocí horkovzdušné pistole odpájejte modul ESP8266. Opatrně ať si nepoškodíte ani ESPčko ani NodeMCU.
- Připájejte barevné vodiče dle obrázku
- Vložte vodiče do konektoru 2x5 s roztečí 2.54mm
- Připojte swifitch a nahrajte software.

Připravili jsme pro vás náš software aby byl začátek co nejsnazší, pokračujte do jeho [repozitáře](http://swifitch.cz/software).



**⚡ PŘI FLASHOVÁNÍ SOFTWARU NEPŘIPOJUJTE SWIFITCH K ROZVODNÉ SÍTI ⚡**

Mělo by to být bezpečné, přesto to nedoporučujeme.

# Software

### Náš základní software 

Pokud jste se rozhodli pro náš software tak postupujte dle README v jeho [repozitáři](http://swifitch.cz/software).

### Vlastní software

Pokud se rozhodnete napsat vlastní software, jen do toho, zde jen pár faktů, které potřebujete znát.

- Relé je ovládané přes pin D1 nebo GPIO5
- Vestavěná LED dioda se spíná přes pin D6 nebo GPIO12

# Krabička

### Vytištěná na 3D tiskárně

Pokud máte přístup ke 3D tiskárně, můžete si vytisknout naší 3D krabičku.





Pokud by jste si rádi navrhli krabičku vlastní a používáte Fusion 360, zde najdete 3D model [Swifitche](http://a360.co/2kX4JSr).

Doporučujeme tisk z ABS, neboť je to bezpečnější materiál pro zařízení napajené z rozvodné sítě.

**NEPOUŽÍVEJTE K TISKU VODIVÉ MATERIÁLY NEBO TY S PŘÍMĚSÍ KOVŮ**

### Kupovaná krabička

Swifitch byl navržen primárně pro umístění do krabičky běžně [dostupné](http://swifitch.cz/cz/enclosure), je však nutné jí drobně upravit, postačí vrtačka a vrtáky na kov.

# Návod na pájení

### Zadní strana

Začněte na zadní straně postupně s SMD součástkami.

**Kondenzátory**

|Pozice|Součástka|
|---|---|
|C1|4.7μF|
|C3|4.7μF|
|C5|4.7μF|
|C6|4.7μF|
|C4|100nF|
|C7|100nF|
|C8|10nF|

**Odpory**

|Pozice|Součástka|
|---|---|
|R3|10kΩ|
|R4|10kΩ|
|R5|10kΩ|
|R6|10kΩ|
|R7|10kΩ|
|R8|2.2kΩ|
|R9|47kΩ|
|R10|160Ω|
|R11|160Ω|

**Zbytek**

|Pozice|Součástka|
|---|---|
|FB1|Feritová perla 600Ω 100MHz|
|D1|BAS86|
|T1|BC817|
|WiFi1|ESP8266-12(E/F/S)|

### Přední strana

Přední strana obsahuje většinově THT součástky, proto začněte s SMD součástkami, které by bylo obtížné pájet později.

**SMD**

|Pozice|Součástka|
|---|---|
|R1|470Ω < Rled < 2kΩ (záleží na LED1)|
|LED1|Barva dle výběru|
|V1|Regulátor Napětí|

**THT**

|Pozice|Součástka|
|---|---|
|DC1|HLK-PM01|
|F2|100°C tepelná pojistka|
|R2|S10K275|
|F1|MST250/0.5A|
|C10|47nF|
|C2|47μF|
|C9|47μF|
|SB1|Pájecí propojka pro volbu D5 nebo výstupu 5V|
|JP1|1x2 kolík|
|JP2|1x2 kolík|
|J3|2x5 kolík|
|RE1|Relé|
|J1|2P svorkovnice|
|J2|3P svorkovnice|

**🎉 HOTOVO 🎉**

# Zásluhy

- návrhy plošných spojů, nápady ohledně elektroniky, výběr vhodných součástek - Miroslav Batěk
- SW, Git Repo, grafika, 3D krabička - Martin Doubek

# Zmíňky

Žlutá pohovka

(https://youtu.be/TU_wt0HFtbs)

# Co dál?

Pokud se vám swifitch zalíbil a chcete ve výbavě chytré domácnosti pokračovat, doporučujeme tyto další projekty.

- [ESP8266 stmívací modul pro LED pásky od uživatele tjclement](https://github.com/tjclement/esp-dimmer-hardware)

Popřípadě tyto IoT platformy, nebo enablery.

- [Homebridge - vlastní HomeKit server](https://github.com/nfarina/homebridge)
	- [Homebridge MQTT plugin](https://github.com/cflurin/homebridge-mqtt)
- [Blynk - plaforma a aplikace pro IoT - lze použít se Swifitchem](https://github.com/blynkkk/blynk-server)
- [Timelapse pájení modulu od jednoho z našich fanoušků - YouTube](https://www.youtube.com/watch?v=yz-Ut0sAMPU)

# Fotografie

 
 


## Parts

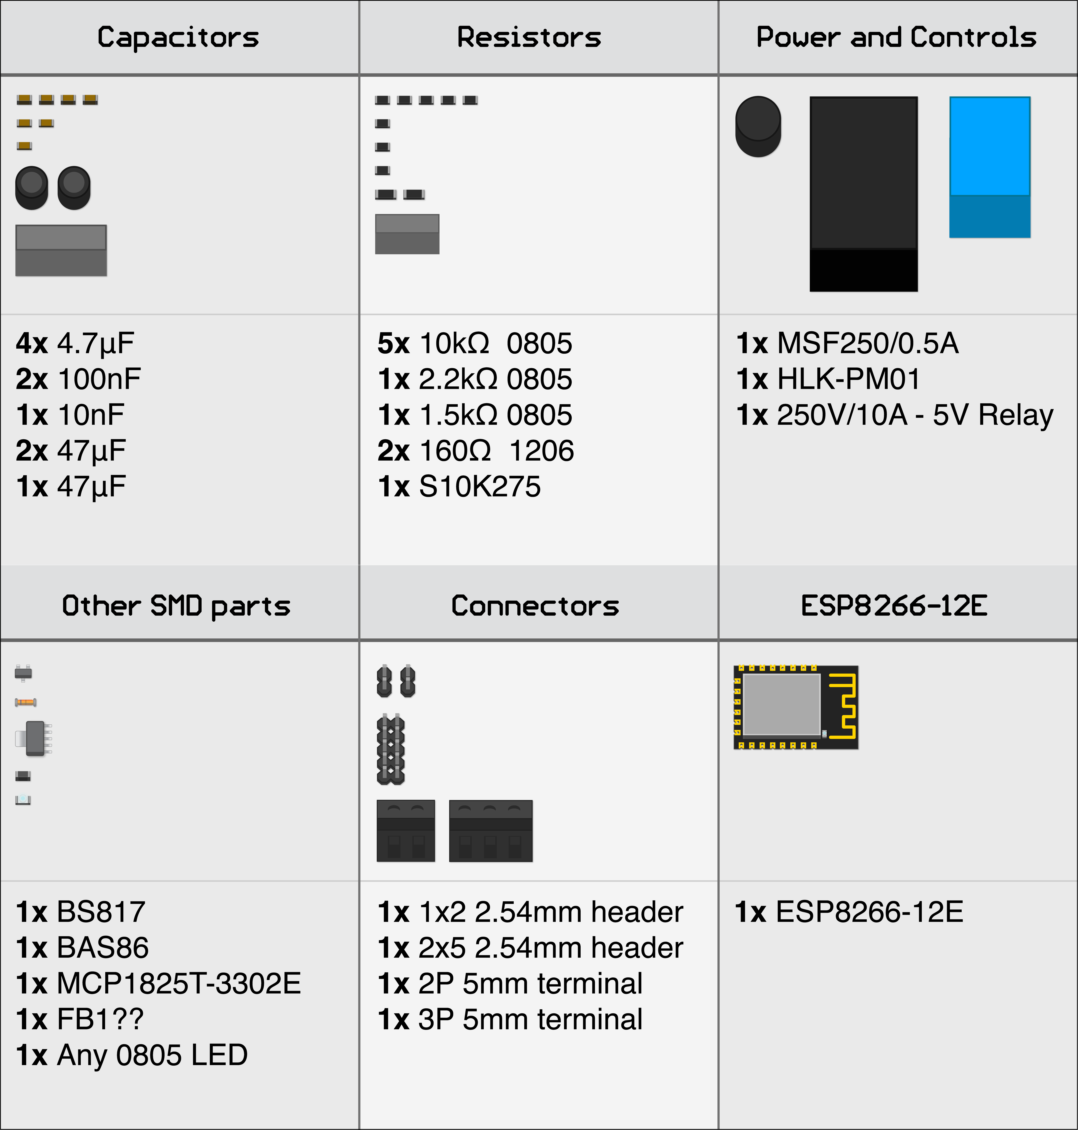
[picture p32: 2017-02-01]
Images/Swifitch_PCB_parts_list_height.png

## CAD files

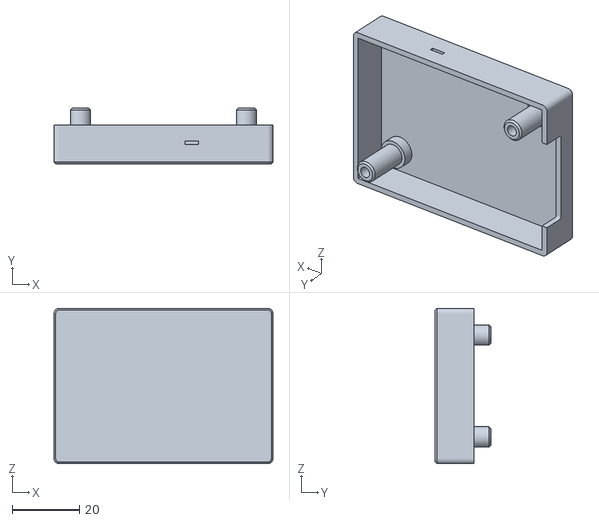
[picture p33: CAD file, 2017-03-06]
Box/Official 3D printed/Bottom.stl
65.2 x 16.6 x 46.2

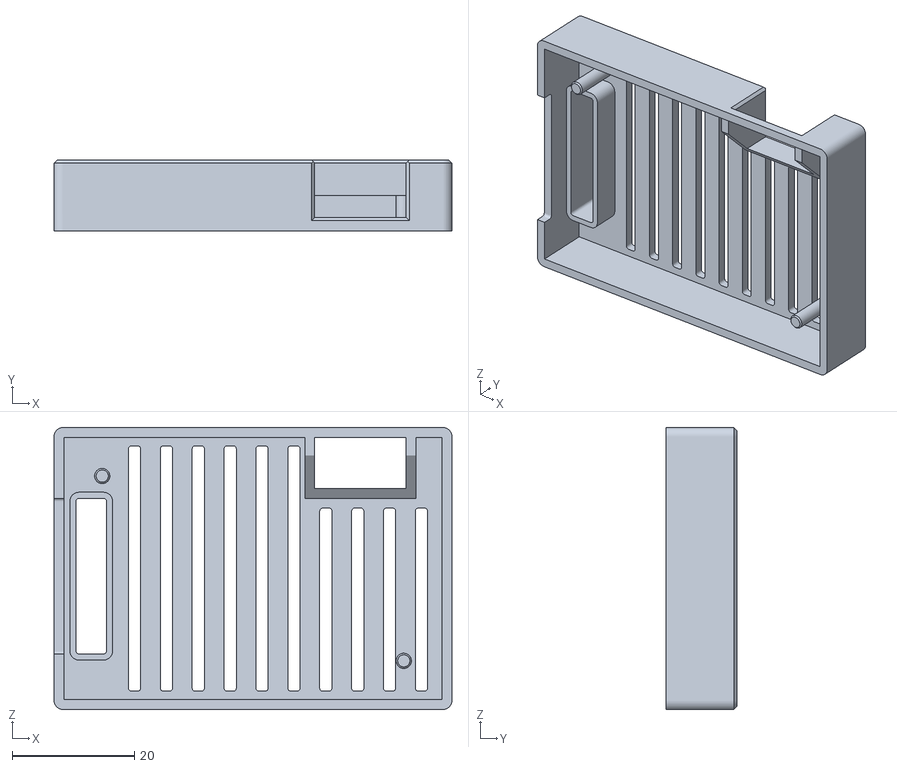
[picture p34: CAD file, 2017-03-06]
Box/Official 3D printed/Top.stl
65.2 x 11.6 x 46.2

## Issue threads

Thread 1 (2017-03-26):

Possible to have the SPI pins available

osos, 2017-03-26:
I really love this work. I have been looking for this diy-HW for a long time. Thank You.

I am interested in applying i2c and/or SPI sensors, displays etc.

Would it be possible to make al the pins available through headers?

ArnieX, 2017-03-26:
Hi,

first of, thanks for the appreciation. To the i2c that's simple as ESP8266 has only SW i2c and you can set whatever GPIO pins you wish I guess default are GPIO 0 and 2 or 0 and 4, I'm not very sure now, those pins are indeed broken out on the header. About SPI I'm really short of knowledge here as I have never used this interface, in case this is too supported only in SW you could likely just set pins you wish to use within your FW.

To keep small footprint we have decided to break out only few pins for additional relay or two or some motion sensor etc. that can extend device's functionality. Breaking all pins would require a lot more space.

Alternatively if SPI pins aren't broken out or possible to set within FW. You could solder wires directly to ESP module in place of SPI pins.

Hope this helps ;), also if you make Swifich, please post pictures [here](https://github.com/ArnieX/swifitch/issues/2).

osos, 2017-03-27:
Hi,

Please see this http://www.pighixxx.com/test/portfolio-items/esp8266/?portfolioID=360

The pins 12, 13, 14 and 15 represent the hardware SPI.

i2c are normally on pin 4 and 5.

ArnieX, 2017-03-27:
Hi,

pins that you are referencing as HW SPI aren't real GPIO, these are only to directly communicate with internal memory. For example ESP8266 12S already do not have these pins as they are useless. Pin 15 is GND.

BR,

Martin

osos, 2017-03-27:
Ok. Not sure I completely understand. Just know that for my SPI enabled sensors etc, these IO-pins are to be used with the libraries available.

Would be fantastic if all available pins could be available on the PIN header on the board.

ArnieX, 2017-03-27:
That is virtually impossible due to size constrains. This device isn't to be allrounder it is meant to switch things on and off and offer limited pin out for sensors or another relays. There is currently no plan to extend the header. The best you could do is to wire pins that you need directly from ESP module by soldering wires to pins directly.

I'm sorry I can't help more here.

BR,

Martin

Closed 2018-01-23.

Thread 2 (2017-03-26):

Photos of finished modules

ArnieX, 2017-03-26:
Hi everyone, please add pictures here in case you manage to make Swifitch yourself. Thank you!

LubergAlexander, 2018-02-02:
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

Just have finished another module - here are some pics :)

ArnieX, 2018-02-02:
Wow, nice pictures!! Thank you. Just one tip thought, wire terminals have groove so they can and should be connected together before soldering and will be nice and flush together.

LubergAlexander, 2018-02-02:
Thanks for the tip! I haven't noticed the grove first, will interconnect them before soldering next time.

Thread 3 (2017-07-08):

How to control multiple relays?

KrishnaPG, 2017-07-08:
Thanks for sharing this good work. It is helpful.

Wondering if you have this design extended for controlling more than one relay. And also, how to make it work with dimmers etc (in the same board alongside with normal relays)?

ArnieX, 2017-07-08:
Hi, this is what header is for. You can connect extra accessories to the board. If you would like it to control big relay board that should be possible if this board would be equipped with I2C. Dimmers would work too but for that I recommend dimmer that is referenced in “What’s next” in readme.

KrishnaPG, 2017-07-08:
Thanks for quick reply @ArnieX Will look into the header functionality. Thanks again for sharing this good work.

ArnieX, 2017-07-08:
You are welcome, hope you will like it if you happen to build few.

KrishnaPG, 2017-07-08:
In the folder which file is the board file? I am trying to experiment with the board to make small changes, such as using nodemcu (in place of esp), and other options such as using mounting headers instead of having to solder etc. Could not find the source files

ArnieX, 2017-07-08:
Sorry, no source file available. Using NodeMCU is overkill. Anyway NodeMCU is good for prototyping, this is actually finished thing. If you want to use NodeMCU the best would be to use other ready made modules, like relay module, etc.

KrishnaPG, 2017-07-10:
Thanks. When sending this design for PCB manufacturer (local) for a quote, they are asking for BOM. Wondering if there is BOM csv file that you can share?

ArnieX, 2017-07-10:
Well, I'm not sure. PCB manufacturers usually need gerber files. I don't know what is BOM, but I can ask my colleague who did the actual PCB design, if he knows what this is.

KrishnaPG, 2017-07-10:
BOM is short for "Bill of Materials". They would need it to assemble components on the PCB (after the creation), and also to give the estimate/quote. Essentially it tells which component goes to which location (on the PCB) and how many needed and what is the exact component brand/value etc.

ArnieX, 2017-07-10:
Hi, this information is in readme. You can therefor assemble BOM file yourself ;)

KrishnaPG, 2017-07-10:
Thanks. Wish I were that expert :)
The system (that generated the gerber etc.), must have auto-generated all these BOM automatically.  It follows certain format. Besides, I want to make sure that their placement mappings (which is not provided in the readme) is correctly captured. Request you to kindly check with your mentioned Friend - he must already be having this BOM file. It would be great help.

KrishnaPG, 2017-07-10:
Also, the placement mapping of these components is important. For example, there are multiple resistors listed in the parts. The generated BOM file keeps the mapping correct.

ArnieX, 2017-07-10:
Just one question. Are you going to make it in big amounts? If not we recommend you to solder manually.

KrishnaPG, 2017-07-10:
Not big amounts. I am more of software guy, so I am asking my friends to help me build samples. In that process, they asked me to get the BOM. It helps them to recreate the board correctly. Even if they have to solder it manually, the would need the mapping (for example, R1 is so and so resistance, C1 is so and so component etc.). Hence the request.

ArnieX, 2017-07-10:
Then again, exact mapping table is included in readme. This should be more than sufficient to do exactly what you need. I use it too when soldering.

Closed 2017-07-10.

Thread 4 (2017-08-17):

PCB design files?

ftruzzi, 2017-08-17:
Hi!

Congrats for this project which looks very clean and well-designed. I was thinking of building something similar myself but I couldn't do it alone and it looks like you already did it!

I see your project is open hardware but I don't see any design files. Can you release them? I would love to add a second relay so that it could still fit into the wall and turn roller shutters up and down (requires two relays).

Another suggestions that comes to mind is to use a 220V - 3.3V AC-DC converter (such as [this](https://www.aliexpress.com/item/ac-dc-3-3v-supply-power-module-110v-220v-264v-to-3-3v-0-9a-small/1976378645.html)) with a 3V-switched relay and get rid of the voltage regulator, but probably 3V relays are not as popular as 5V ones.

ArnieX, 2017-08-29:
Hi,

sorry for later reply.

220V-3V3 AC-DC wasn't used as it is more expensive and not as stable as ESP might require, but you are free to test it out ;). I'm not sure how about 3V3 relays but they are less popular as most of them are sold for Arduino hackers and those require 5V.

Design files are now added to repository.

Martin

ArnieX, 2018-01-23:
Hi @ftruzzi,

have you done some changes to the board yet? Feel free to share. Thanks.

BR,

Martin

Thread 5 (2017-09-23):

Doubt

hkauroberoi, 2017-09-23:
Hi,

The project is simply awesome and I'm in process of ordering the PCB's. However, I'm confused when you say "_Keep in mind that each board are actually two swifitches ;)_ as there's only one relay or am I missing something.
Further, the analog switch function - does this mean I can use a conventional wall switch to control the load along with web control?
Thanks

ArnieX, 2017-09-23:
Hi,

thank you for kind words ;).

- 1 PCB board is actually two boards that you will break in middle, this is information for people to not order more than they really need as when you order 10pcs of PCB it will last for 20 individual modules.

- Yes you are right, 1 swifitch is 1 relay so you can control 1 thing

- Analog switch function is great if you have full N/L in under your switches at home. Usually wall switch only connect L between power source and light. N is usually not available. If you have separate N/L lines under your wall switches you are good to go with this function. You will connect the physical switch with low voltage line and one resistor to Swifitch header.

Good luck with building it and if you will remember, share your photos and experience here on GitHub, thanks.

hkauroberoi, 2017-09-23:
Thank you so much for such a prompt response.
The analog switch function is simply great - hats off to you !! I'll be more than happy to post the images.

Thanks.

Closed 2017-09-23.

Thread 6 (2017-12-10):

Using swifitch with existing switches & 110v

LubergAlexander, 2017-12-10:
Hi,

First of all, huge thanks for this awesome project!

I would like to try to install it behind existing light switches and rewire them so I can reuse the actual physical switch to control the lights + have the ability to do it remotely.

1) It looks like the main component which would depend on the mains voltage is the Hi-Link HLK-PM01, and it seems that its compatible with both 220 and 110V. Do you know about any other components which may be affected? Can it be used in the US?

2) Second question is regarding the physical switch. I read the firmware source code, and it looks like I can connect the 'analog' switch to D4... Have you tried to use it in a similar setup? I want to have both a physical switch + remote control.

3) if the previous question is indeed possible, can you please explain how to wire it? I think it will be beneficial to add to Readme as well. (How to connect the existing switch to D4 so it acts as a button + connecting the mains to swifitch)

ArnieX, 2017-12-10:
Hi Alexander,

I'm happy you like it ;)

1, I don't know about 110V but I think that HLK-PM01 is capable to run on 110V too. So it should be ok in US.

2, It's actually D2 and yes you can connect analog switch. What you need is L/N cables under switch to power Swifitch. It need to have both and N isn't always available under switches so it depends on your house wiring.

3, Wiring of analog switch is easy, just completely remove any high voltage cablest from the analog switch and connect the contact to 3V3 from Swifitch to analog switch, output from analog switch to pin D2 and then bridge D2 and GND on Swifitch which will pulldown the D2 pin to register correctly when analog switch is disconnected from 3V3. All the functionality should be in firmware itself, I have done the changes for my friend who has wiring so he could use it this way and he is happy with that. Thought it wasn't designed with analog switch in mind.

Hope this is clear ;), otherwise let me know.

BR,

Martin

LubergAlexander, 2017-12-10:
Thanks for a quick reply!

I will later remove one of the faceplates to figure out the current wiring and will post it here. Still a little bit unclear to me.

for the 3. Thanks! I was thinking why not to connect D2 to the switch and the other end to the GND, and set D2 to INPUT_PULLUP in the firmware, I thought this way it will not require bridging and will be less wires :) I have recently connected a button to an arduino this way, correct me if Im wrong.

ArnieX, 2017-12-10:
Hey good point ;) I wasn't aware of this possibility. I have draw quick scheme how to wire it up.

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

Could you please when you try that out with INPUT_PULLUP push this change to swifitch-software repository? I will review and approve. Thanks in advance.

Martin

ArnieX, 2017-12-10:
So if I get it right you suggest this scheme and enabling INPUT_PULLUP option?

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

LubergAlexander, 2017-12-10:
Yes

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

LubergAlexander, 2017-12-10:
Also in the firmware it will require minor changes to compare digitalRead of D2, with LOW instead of HIGH

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

ArnieX, 2017-12-10:
OK if the change is just pinMode(D2,INPUT_PULLUP); and swapping LOW/HIGH I will do the change and test it. Will include the scheme too.

LubergAlexander, 2017-12-10:
Thanks! Great! I will try to figure out my house wiring later today and
will post pictures/scheme on the ticket.

On Sun, Dec 10, 2017 at 10:32 AM, Martin Doubek <notifications@github.com>
wrote:

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

ArnieX, 2017-12-10:
I have tested it out and it works flawlessly, I have already pushed it to the repo and added credits to readme to thank you for the idea ;), check it out.

LubergAlexander, 2017-12-18:
@ArnieX Here is the diagram of my light switch wiring:
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

the light switch itself has 2 black wires and 1 copper(ground) connected. 2 white wires(neutral) are connected together

ArnieX, 2017-12-18:
Hi Alex,

you are good to go. I would disconnect Ground wire from the switch as this is not needed when it is connected to low power part of swifitch. Then you need to connect neutral to N, black input to L (line), then black output wire to NC or NO this means Normaly Open or Close. Close is that when there is no power to relay it is ON, when you choose Normaly Open it means that the connected appliance is OFF when there is no power to relay. Than programatically you change the default state by applying power to relay. Just pick one, try how it works for you and you could change that later. My recommendation is to start with NO. Then you need to replace those black wires with low voltage ones and connect swifitch to switch pin D2 and GND. Make sure no high voltage cables are connected to the switch anymore. If you are unsure I’m not electrician and I do not know US standards so if not sure let someone to check if you have it wired correctly. Please do not get yourself killed. Let me know how it went. It should be pretty straightforward.

So N (white), L (black input comming from bottom), NO (black going to light).

Make sure that white wire go to swifitch and still continue to light, it won’t work otherwise.

LubergAlexander, 2017-12-18:
Thank you very much!
Also forgot to ask: What would you recommend for two-way and three-way switches(when you control same light from multiple locations).
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

Do I need to somehow wire the swifitches in a similar way? Or this should be solved on MQTT level using rules? I can imagine its possible to write a handler which just accepts a message over message queue to flip the status of the boolean without actually toggling the relay. Would be cool to implement multi-way switches on that level(will send a pull request if I do that)

ArnieX, 2017-12-18:
This is always the hardest scenario ;). You basically need to install ONE swifitch that will actually toggle the light. In the other switch you will need to sacrifice one swifitch to not do anything else other than sending command that switch was flipped. Then the other swifitch will toggle relay, this logic is better to do in Node RED than directly in swifitches. For the "dumb" swifitch you do not need to solder relay, diode and transistor at all and save it for other swifitch. Share some video when you have it working ;).

LubergAlexander, 2017-12-18:
Thanks! I will

ArnieX, 2018-01-23:
Hi @LubergAlexander,

how is your project going?

BR,

Martin

LubergAlexander, 2018-01-23:
3 more components left to solder, ordered incorrect voltage regulators and
fuses. It is in progress - I will reply after I am done with pictures and
will probably have updates for the software.

On Tue, Jan 23, 2018 at 12:34 PM, Martin Doubek <notifications@github.com>
wrote:

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

ArnieX, 2018-01-23:
Yeah that can happen ;). Otherwise awesome. Looking forward for the code updates. I'm open to any improvements.

LubergAlexander, 2018-01-23:
@ArnieX I will get back to you on that, but while I am still building the first one, here are a few improvements I would like to make:

1) Implement configurable optimistic strategy. At the moment when you toggle the button it switches the relay first, and then sends the update to mqtt. I would like to add a checkbox on the configuration screen: optimistic: true/false. If disabled, it would send the request to mqtt first and will switch the relay only if got the approval from the server. This would be useful to disable certain switches programmatically(for switch controlled outlets for example)

2) HTTPS support for MQTT transport. I know that ESP8266 is pretty slow, but I saw some solutions on SSL implementation, would like to try them.

3) Some code cleanup, code style and unit tests if I ll have time :)

ArnieX, 2018-01-23:
Sounds interesting.

1, I can't imagine usecase for this, but may have some for some people. How about just adding topic to disable/enable analog switch? That would maybe do this easier. Instead of asking for permission on demand, it will already know if it has it or not.

2, Good luck ;). I don't think it's necessary for local setup but may be good for remote locations.

3, Hmm ;) this sounds like I still got lot to learn :D, but unit tests could be good to have thought.

LubergAlexander, 2018-02-02:
@ArnieX quick update - finally tried to connect it - worked the first try! Toggled the lights with MQTT commands. I will do some cleanup, want to embed a couple boxes behind existing switches and then will post a connection diagram and pics!

ArnieX, 2018-02-02:
Well done! Congratulation ;). Looking forward.

Closed 2017-12-18.

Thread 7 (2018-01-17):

PCB design in ascii format?

dicastro, 2018-01-17:
Hi,

I am trying to create and use a swifitch, this is an idea I already had in mind, and looking for an open source/hardware solution, I have arrived to your github repos. I think your solution is a really great solution, and a ready to use solution in a real scenario (not a prototype).

I am a software developper and my knowledge about hardware and soldering skill is limited. So I am trying to import your design in this site: https://easyeda.com. In this site you can design a circuit, choose the components, design a pcb and after that you can print the pcb and buy all the components easily (I am not sure if they also send you the pcb with the components assembled, that should be great). This way it will be super easy to buy all required components for N swifitchs.

This site (https://easyeda.com) supports importing an Altium project. I am trying this option, using your published design files, but I get following error:

`Bad file format, ensure your file is Altium ASCII v5.0 format (*PCB/Schematic only*)`

1. Could you please add to the repo the design files in this format?
2. Do you know an alternative site to mentioned one, that is compatible with your design files, to do the same thing: print the pcb and buy all the components at once
3. The mentioned site also allows to share a design, it should be great that you publish your design (choosing the right components) in this site. While your are designing and choosing components you can get easily the BOM and the cost of all components to get an idea of total cost. I know that requesting this is too much, but I had to try!

Thank you very much for sharing this awesome project and making life easier to software developers with limited hardware knowledge but with great ideas.

ArnieX, 2018-01-17:
Hi,

thanks for taking time to write in. I think you won't find better documentation in either OpenSource Hardware projects. It is very straight forward to buy all the items you need. There are amounts per swifitch and links to shops where you can easily order all of it. PCB is very easy and cheap to order via seeedstudio. Soldering was done by many beginners yet and all I'm in contact with were able to finish it properly ;). So I strongly think, you should be able to.

I will have a look at provided URL but I'm pretty sure that it will come at cost. No-one will be able to provide you with PCB and complete set of parts without asking for some extra money for the time to collect it. Not even mentioning if they will do the soldering for you. Those services are often very expensive.

About the file format, I will ask my friend who did the design if he knows how to get you what you need for easyeda.com.

BTW before swifitch I had zero HW knowledge and not even great SW one. So if I could do it, so can you and anyone else ;). With this in mind I tried to do the documentation as precise and as easy to follow as possible.

I'm happy you like it. Will be back with info you requested if I can get it.

dicastro, 2018-01-17:
In EasyEDA while you are designing the circuit, you can link a component (ex: a 1 ohm resistor) to a concrete resistor offered by a concrete provider. In such a way when the circuit design is finished you have the list of all specific components offered by providers and their corresponding price.

EasyEDA has also a component store, so the sell an extensive list of components. Once the circuit is finished (with all components linked) you can make an order of all components in one click!

Ok, I'll wait for your answer concerning the PCB design in ASCII format.

ArnieX, 2018-01-17:
Well I did quick research and EasyEDA isn't offering many crucial parts. Fuses (temperature, shortcircuit), varistor, AC-DC power source, LDO regulator, ferrite bead, some capacitors etc., most other parts they have but at highet price tag than could be purchased from other sources. So I do not think, they are going to provide you all parts and if so, not at a good price.

dicastro, 2018-01-17:
Thank you very much for taking time to review EasyEDA, I really appreciate it.

I will take into account your research and I will purchase the components in other sources.

ArnieX, 2018-01-17:
Well it's up to you anyways ;), it's just my opinion, that it would actually be a lot more struggle than following documentation as others did successfuly.

dicastro, 2018-01-17:
I was trying to find a _one click_ solution and to avoid _AliExpress_ and their very long shipping times.

ArnieX, 2018-01-17:
Yeah I understand, but that is unfortunately inevitable ;), we all went this way and survived. Imagine how long it took to prototype with those shipping times. Anyway for PCB you will wait around two weeks and most of the parts from Ali will arrive in two to three weeks if you order now. Watch for Chinese New Year which is about to begin in february, then the wait could be longer. If you order now you should have all parts mid or end of february. That is still ok.

If you have additional questions or some parts links are outdated (which it shouldn't but can happen), let me know and I will assist you as much as I could. When you finish swifitches just post some pictures here in issue which is asking for pictures. It's great to see people having fun and making those.

dicastro, 2018-01-18:
Today I have purchased everything. I have bought pieces enough to build a few swifiches!

So in few weeks I hope to have received everything and to be able to assemble it successfully.

I have a 3D printer, so meanwhile I am going to print the box

ArnieX, 2018-01-18:
Awesome! Yeah 3D printer is a big helper in many projects. I have Prusa i3 MK2S. Let me know then.

Closed 2018-01-17.

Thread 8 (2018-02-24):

Zmenšení (Swifitch Mini)

iChUdY, 2018-02-24:
Ahoj,

v první řadě bych chtěl moc poděkovat za to, že takový projekt vůbec vznikl a byl dotažen do funkčního konce. Opravdu tleskám ve stoje a klobouk dolů. ESP8622 je prostě super chip a určitě si vaší variantu někdy zkusím sám sestavit.

U mě toto pobláznění vzniklo při koupi ESP8622 produktu Sonoff Basic, který je sám o sobě úplně o ničem, ale s vlastním firmwarem, mqtt, homebridge, HomeKit, Apple TV je to pro mě nejzajímavější produkt IoT historie. V ČR se dá koupit za 229,- (i s krabičkou 😉) z banggood za 109,- free ship👍🏻

A teď k podstatě této issue. Nejde ani tolik o to, že Sonoff vyjde levnějš a s vynaložením mnohem menšího úsilí(přidaná hodnota radosti z úspěchu sestavením vlastního ESP8622 spínače je nevyčíslitelná), ale Sonoff je prostě a jednoduše mnohem menší a většinou se vejde za běžní nástěnný vypínač(GPIO14 má samozřejmě taky).

Plánuje se varianta Swifitch Mini ?

Ještě jednou moc díky za vaší práci a přeji mnoho dalších úspěchů.

S pozdravem Standa ✋🏻

Fotky z mého flashování Sonoff Basic:
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

ArnieX, 2018-02-24:
Ahoj Stando,

díky za pochvalu, moc nás to těší. O Sonoffu jsme samozřejmě věděli i v době kdy jsme dělali Swifitch ale naším cílem bylo udělat hlavně bezpečný modul a superjednoduše sestavitelný i pro úplné laiky. Nějaké pojistky na sonoffu jsou také ale nevím jak moc je to celkově bezpečné. Jinak u takového zařízení jako je Sonoff rapidně klesá množství lidí, co takový modul dokáží sestavit a tak aby si neublížili, například ten zdroj 230VAC->5VDC (nebo na kolik to stepdownují) je prostě složitější postavit. O menším modulu jsme se bavili ale v současné chvíli pracujeme na něčem mnohem úžasnějším. Je možné že se ke Swifitchi časem vrátíme a uděláme upravenou verzi. Jinak jsou uživatelé Swifitche co jej mají zabudovaný pod vypínači také a funguje jim to skvěle. Rád bych tě teď potěšil informací o Swifitch Mini verzi ale zatím bohužel ;). Každopádně určitě si Swifitch postav, je to parádní pocit udělat něco svého a pak se pochlub výsledkem.

Martin Doubek

iChUdY, 2018-03-01:
Ahoj,
jsem zvědav na čem úžasným pracujete. Těším se na výsledek.

Našel jsem asi nejmenší esp switch zde:
http://tinkerman.cat/the-espurna-board-a-smart-wall-switch-with-power-monitoring/#lightbox-gallery-crvo/0/

...používají stejný zdroj i SoC a navíc ještě s HLW8012.

ArnieX, 2018-03-02:
Také pěkné ;), je toho celkem dost. Netvrdím že jsme udělali naprosto unikátní zařízení.

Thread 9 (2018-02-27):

How to desolder ESP8266 from NodeMCU

dicastro, 2018-02-27:
My soldering/desoldering knowledge is very limited. How could I desolder ESP from NodeMCU?

Do you have any recommended tool? Do you have some tips? I have already tried with a normal soldering tool, and it seems impossible to me.

ArnieX, 2018-02-27:
You need hot air for that ;) and do it very carefully.

LubergAlexander, 2018-02-27:
@dicastro I have tried to desolder it with a regular soldering iron and killed the chip and still wasn't able to desolder it, so a heatgun is a must :) If you have an arduino around - you can try flashing with it: https://github.com/ArnieX/swifitch-software#how-to-flash-with-arduino-uno

dicastro, 2018-02-27:
I've found this video (https://youtu.be/zwp9E37ioVw) where it is explained how to make the connection without desoldering esp from NodeMCU. I'll try this option. I do not want to buy a heatgun just to desolder one thing.

dicastro, 2018-03-21:
Finally I would like to desolder ESP from NodeMCU. I bought a heatgun, but after 10 minutes of use it is broken.

*Which brand of heatgun do you recommend me?* I would like one that lasts more than 10 minutes!

I do not know I the ones that I've seen in Amazon are good quality ones (the one that I bought was from Amazon).

I have looked in TME site and I've found these ones (there are more but I do not want to spend a lot of money):

- [SOLDER PEAK SP-1011DLR](https://www.tme.eu/gb/details/sp-1011dlr/hot-air-stations/solder-peak/)
- [ATTEN AT850D](https://www.tme.eu/gb/details/at850d/hot-air-stations/atten/)
- [THERMALTRONICS TMT-HA200](https://www.tme.eu/gb/details/tmt-ha200/hot-air-stations/thermaltronics/)
- [THERMALTRONICS TMT-HA300](https://www.tme.eu/gb/details/tmt-ha300/hot-air-stations/thermaltronics/)
- [ZD-912](https://www.tme.eu/gb/details/zd-912/hot-air-stations/)

*Do you know any of these ones?*

dicastro, 2018-03-21:
I've already bought one, so I close the issue.

Cross fingers!

ArnieX, 2018-03-21:
:D sorry I didn't reply, I was so busy today. But I wouldn't help you anyway as I do not have any heatgun except gas one, which is not really good for this job.

dicastro, 2018-03-24:
Hi again,

I still have a problem with the power of swificth.

What I've done:

- I have desoldered esp8266 form nodemcu, using my brand new soldering station
- I have connected the wires between nodemcu and swifitch as your diagram says
- I have flashed swifitch firmware
- I have powered swifitch plugging nodemcu to a USB of my laptop
- **Swifitch does not work**
    - The led gets red
    - I see the AP
    - When I try to connect from my laptop to de AP, the led starts blinking and it never connects

**However, if I power the swifitch plugging nodemcu to a mobile phone charger, it works.**

So I supose that the USB of my laptop has no current enough. **I am really interested in powering nodemcu from my laptop** to be able to see serial traces to debug the code (I am doing some changes in code).

- Do you know why with my laptop it doesn't work? (It is a brand new one, less than a year)
- Have you ever had this problem? Is there a workaround? Can I use an external power source, and connect swifitch to the laptop to see traces?

I am desperated!!

dicastro, 2018-03-25:
Thank you for your help!

I've tried with 2 laptops (both with windows) and with one raspberry pi (activating max_usb_current configuration option). And always with the same result. I am not able to connect to swifitch AP.

I've tried to create a "hello world" firmware (without any wifi connection) and everything works perfectly. I can power swificht plugging nodemcu to my laptop, and I am able to see serial traces. When I modify "hello world" firmware to connect to my home wifi, it doesn't work.

Tomorrow I am going to test swifitch at work, there I've got an iMac, and I have some collegues with MacBooks.

LubergAlexander, 2018-03-25:
I had exactly the same problem after trying to desolder the esp from
nodemcu with a soldering iron:) I have overheated and damaged the chip, it
did boot up initially, and I was able to run non wifi code, but if I tried
to connect to my AP - it crashed.

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

dicastro, 2018-03-25:
The ESP that I've used in the swifitch is not the one that I've desoldered from NodeMCU. So I think I do not have the same problem.

I will try to explain myself better.

Case A (firmware without Wifi connection)

```
// Case A.1
Swifitch <-> NodeMCU <-> Laptop USB

// It works but It is not stable, sometimes it reboots

---

// Case A.2
Swifitch <-> NodeMCU <-> Mobile USB Chager

// It works and It is stable. The issue is that I can't see serial traces un this way
```

Case B (firmware with Wifi connection)

```
// Case B.1
Swifitch <-> NodeMCU <-> Laptop USB

// It does NOT work, it reboots all the time

---

// Case B.2
Swifitch <-> NodeMCU <-> Mobile USB Chager

// It works and It is stable. The issue is that I can't see serial traces un this way
```

The only explanation that I've found os that the current supplied by my laptop USB is not enough.

ArnieX, 2018-03-25:
"The only explanation that I've found is that the current supplied by my laptop USB is not enough."

That could very well be the issue, my recommendation is to get USB doctor: https://www.aliexpress.com/item/Digital-Dispay-3V-30V-Mini-Current-Voltage-Charger-Capacity-Tester-USB-Doctor-qc2-0-3-0/32686482158.html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,searchweb201602_5_10152_10151_10065_10068_10344_10342_10343_10340_10341_10696_10084_10083_10618_10304_10307_10302_5711215_10313_10059_10534_100031_10103_10624_10623_10622_10621_10620,searchweb201603_1,ppcSwitch_4&algo_expid=4fe0352c-214c-4ea8-aa4e-f8a4120dfb21-8&algo_pvid=4fe0352c-214c-4ea8-aa4e-f8a4120dfb21&priceBeautifyAB=0

dicastro, 2018-03-26:
This morning I've done a test with an iMac at work. It works better, I am able to connect to the swificth AP. But it is not stable enough, when I toggle the relay it restarts. So I think there is not current enough yet.

What I've tried is to have swificht powered to the main current and to the usb at same time.

```
Swifitch <-> NodeMCU <-> Laptop USB
    ^
    |
    +--> Main current (220 V AC)
```

**Can this option damage the swifitch?**

ArnieX, 2018-03-26:
OUCH!!! Have your read documentation properly? NEVER EVER connect mains and computer simultaneously. It may not hurt anything, but it is at least very bad idea. It could more likely destroy your computer than swifitch but still, please, don't do this. For your safety.

dicastro, 2018-03-26:
I did not remember that detail :-P

Nothing has exploded! But I am not going to do it again.

I am considering to buy this [dual usb cable](https://www.amazon.es/dp/B0047AALW6/?coliid=I1ZUP936VAUPJL&colid=1WFY4HLP30GFM&psc=0&ref_=lv_ov_lig_dp_it) to have extra power.

I've also bought the usb doctor that you recommended me to see the differences between the current of mac's usb and the current of windows/linux's usb

ArnieX, 2018-03-26:
That cable looks like really good idea ;)

dicastro, 2018-03-27:
With the _dual usb cable_, and connecting the serial wire to my laptop and the power wire to a mobile phone charger, it works like a charm!

> I have had some issue using a charger of an android device (2A charger of a samsung tablet), it wasn't stable. Finally I've used a 1A Iphone mobile charger. I do not understand why.

Thank you very much for your help!

Closed 2018-03-27.

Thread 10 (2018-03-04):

ESP8266 vs ESP12S

dicastro, 2018-03-04:
I have just realized that the link for the ESP8266 points to an ESP12S. This one (ESP12S has only connectors in both laterals only). Is this one compatible?

I have bought all the components following your links. Maybe aliexpress has changed the component?

(All the photos in your repo have swifitches using ESP8266)

ArnieX, 2018-03-04:
Yes ESP8266-12S is compatible. It is newer version and those pins on the back aren’t used for anything. I do not even solder these when using 12E or 12F versions. Basically most ESP versions from 7 up are supported. But I suggest you stick with 12E/F/S.

dicastro, 2018-03-04:
Thank you!

Closed 2018-03-04.

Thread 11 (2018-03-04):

Altium Designer Library

KoolEngineer, 2018-03-04:
Hi ArnieX,

First of all thank you for providing us with such a nice project. Excellent work! I want to add series of relay (6 no.) in my project. I tried loading the design files provided by you in Altium but I am not able to load exact footprints, symbols and 3D models. So will you please add these files in the repository so that I can use it for my project. It will be helpful for us in our projects. Pardon me if I have hurt your sentiments.

Best Regards,
Kool Engineer

ArnieX, 2018-03-04:
Hi,

I'm not the one who did the design in Altium but I'm pretty sure there were no 3D models used in there.

BR,

Martin

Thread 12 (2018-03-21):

Can swifitch relay work with DC?

dicastro, 2018-03-21:
I do not know if this is an stupid question. I would like to know if it is possible to power swifitch with AC and use the relay for a DC circuit.

I have a really simple intercom at home and I am wondering if I could use swifitch to bypass the button of the intercom. Could I power swifitch, puggling it to main current (220V AC), and use swifitch's relay to bypass the button of the intercom, which works with DC? (it has 8.8 V and 65 mA)

ArnieX, 2018-03-21:
No because input voltage is also output voltage, it is connected on the board. So NO. But for DC transistor is better anyways. You can build simple circuit with the same transistor BCM817 that is used on swifitch, control it with swifitch GPIO and you will control this button. But I can't tell you how exactly to make this circuit because well I do not know myself :D.

dicastro, 2018-03-21:
Ok. Thank you!

I am wondering also if you, the team that has designed/developped swifitch, would be willing to make an adhoc pcb design (payed, of course)?

I think that swifitch is really well designed and I am interested in developping other modules, but I do not have the hardware knowledge.

ArnieX, 2018-03-21:
What kind of stuff are you thinking about?

dicastro, 2018-03-23:
Sorry for the delay. I am thinking in several things related to domotics.

1. I would like to have a swifitch with two relays, but conserving the reduced size. At home I have some double switches to control the lights of different zones in same room. I would like to have a swifitch inside this switches (this double switch is the same size as the single switch).
1. I would like to have a swifitch powered with DC and with a "relay" for DC (I think that for DC transistors are the right option, instead of relays). The use case is to have a swifitch to control my home's intercom, to open the external door. This intercom is powered with DC (8.8 V and 0.65mA). I would like to power the swifitch with the intercom's power. I know that maybe 65mA is not enough, so I've thought that it could be possible to have the swifitch powered with a rechargeable battery, and use the power of the intercom to recharge the swifitch's battery. I am planning to deploy this solution in different places, and all places won't have the same conditions, I mean same voltage or current. So I wonder if it would be possible to have something that worked with a range of input voltage (ex: from 5V to 24V).
1. I would also like to have something to control motorized blinds. I have not investigated anything about this subject. I have some motorized blinds but I do not know how do they work. A simple relay should be enough? How to control the sense of movement? How about security mechanisms? What if my cats are in the middle while the bilnds are closing?

ArnieX, 2018-03-23:
Hi @dicastro

1, Yeah that would be nice, no promises thought, we are working on something else right now. We may revisit swifitch at later date.

2, You could do that, 5V should be possible to directly connect to the regulator (ie output of AC/DC converter - which wouldn't be there), or you could use some small DC/DC converter which will allow you to turn swifitch directly to DC operated. You will need to set this regulator to output 5V, then you will have switchable input voltage on relay. So it could work anywhere from 7V to 28V. But you need also sufficient current on output, at least of 500mA@5V so that the ESP has enough power.

3, Usually relay will do as signal to the blinds. But you need to discuss this with manufacturer of your blinds.

Closed 2018-03-24.

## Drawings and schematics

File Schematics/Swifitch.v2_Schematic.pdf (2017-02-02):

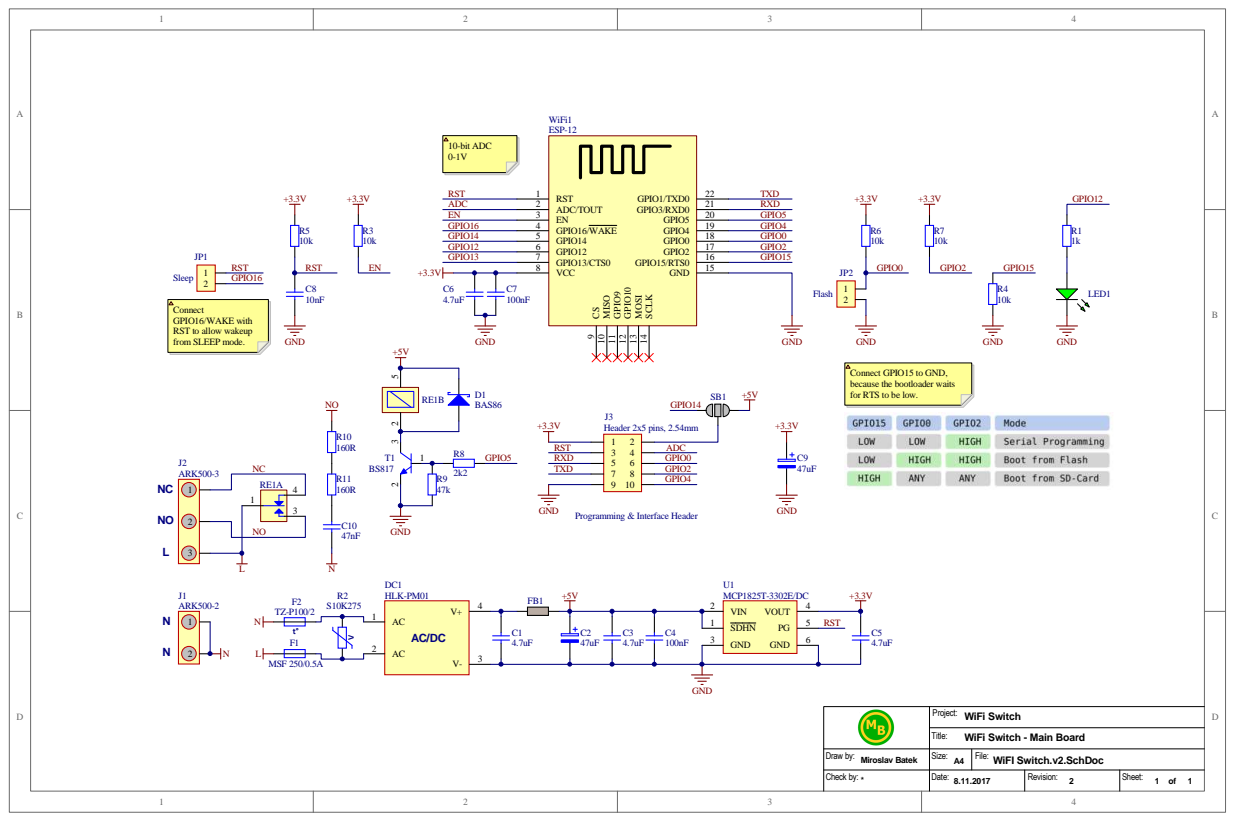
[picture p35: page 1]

Connect
GPIO16/WAKE with
RST to allow wakeup
from SLEEP mode.

Connect GPIO15 to GND,
because the bootloader waits
for RTS to be low.

Project:
WiFi Switch
WiFi Switch - Main Board

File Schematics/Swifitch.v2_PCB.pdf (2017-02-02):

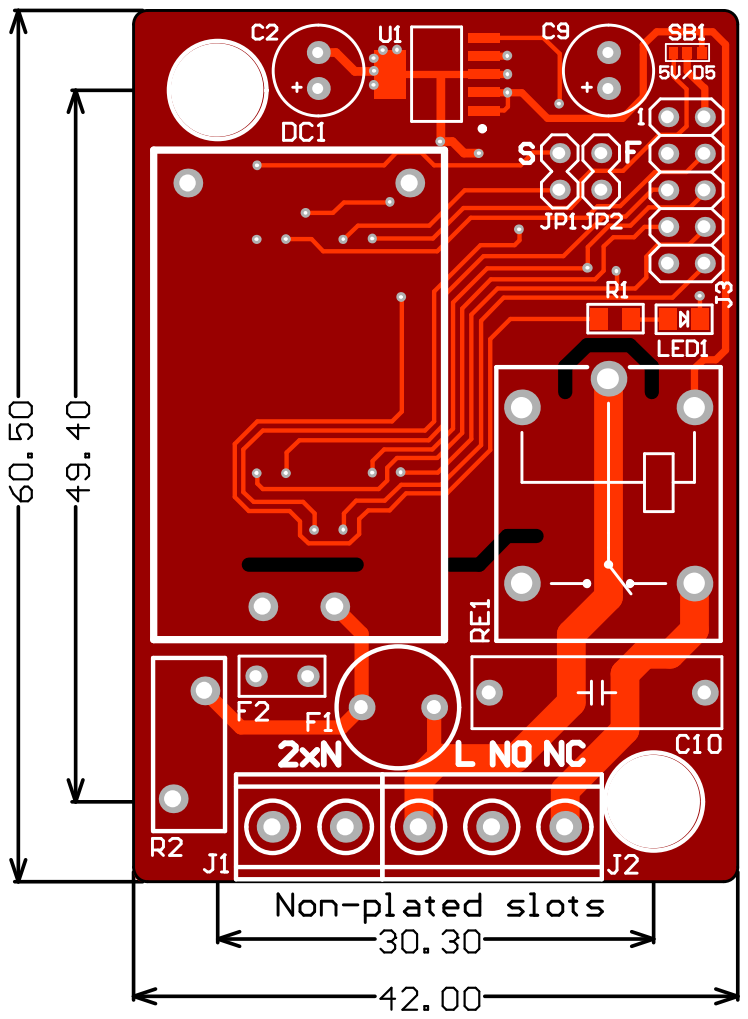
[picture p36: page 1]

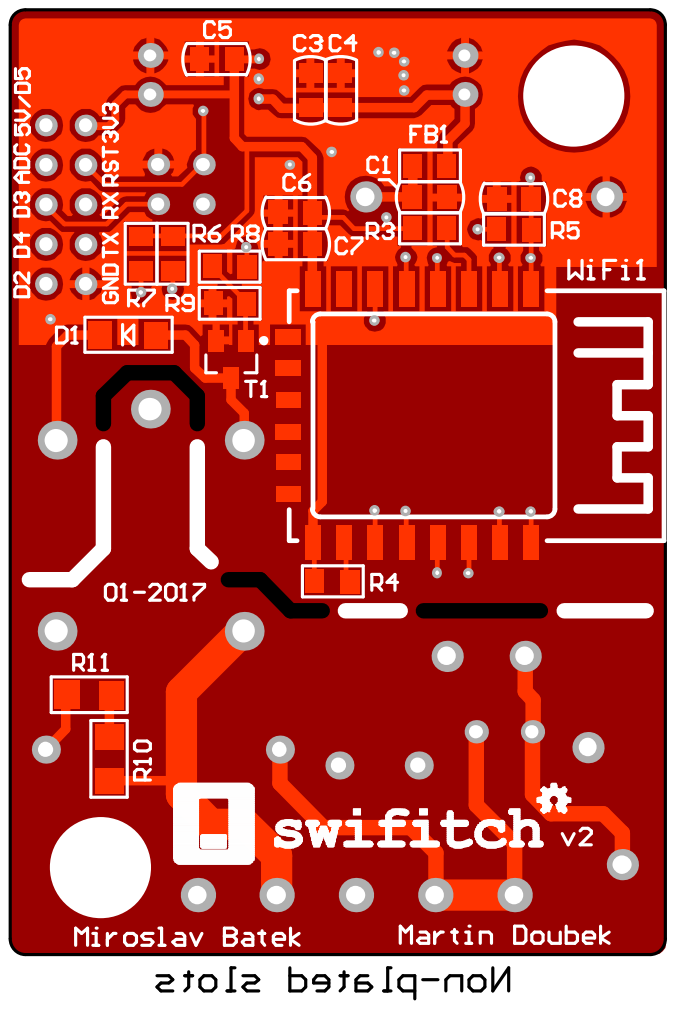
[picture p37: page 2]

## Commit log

2017-02-02 New parts table with shop links, added schematics and PCB preview in /Schematics folder.
2017-02-02 Fixed capacitor value
2017-02-06 Minor fixes in gerber files, D5/5V label on SB1 was flipped. Images in readme were updated accordingly.
2017-02-10 SeeedStudio Fusion PCB link addition
2017-02-14 3D printed box bottom without ventilation holes
    [Bottom_No_Holes.stl]
2017-02-19 New box design, new images, etc.
    [Bottom.stl, Bottom_No_Holes.stl, Top.stl]
2017-03-06 Slight change in box connection between parts - pins
    [Bottom.stl, Top.stl]
2017-03-07 Box was printed by one of our fans and it works great, so the statement that it is experimental was removed.
2017-06-19 Soldering timelapse
2017-08-29 Added PCB design files in Altium Designer
    [WiFI Switch.v2.Panel.PcbDoc, WiFI Switch.v2.PcbDoc, WiFI Switch.v2.PrjPcb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]
2017-12-29 Update README_CZ.md
    MSF => MST fuse
2017-12-29 Update README.md
    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
2018-02-23 Adding image for physical switch connection scheme.
